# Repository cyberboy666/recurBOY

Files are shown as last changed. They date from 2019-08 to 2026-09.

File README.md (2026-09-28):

# recurBOY

### a rpi0 video-instrument – created in collaboration with Guergana Tzatchkova



- this circuit is distributed by __UNDERSCORES__ - _an open video hardware label_ : it is available to purchase - as a pcb, kit or assembled unit - at [underscores.shop](https://underscores.shop/recurboy/)
- the schematic for the circuit can be found [here](/hardware/schematic.pdf)
- the pcb gerber files for the lastest version can be found [here](/hardware/gerber_latest.zip)
- interactive BOM is [here](https://htmlpreview.github.io/?https://github.com/cyberboy666/recurBOY/blob/main/hardware/bom/ibom.html)
- link to latest rpi image is [here](https://github.com/cyberboy666/recurBOY/releases/latest)
- link to FAQ/TROUBLESHOOTING page can be found [here](https://github.com/cyberboy666/recurBOY/wiki/recurBOY-FAQ---TROUBLESHOOTING-guide)
- consider [donating](https://opencollective.com/underscores) to the underscores project to help us continue creating for the commons

## description

_recurBOY_ is a stand-alone digital video synthesizer and sampler. it can trigger clips and run shaders to create and manipulate sd video. 

- outputs sd video over composite or hdmi
- 2 source modes to generate video : sampler and shaders
- process any source with additional FX
- control shader/fx parameters directly with 4x knobs or externally with 4x cv inputs
- all inputs also controllable via usb-midi
- process external video through compatible usb capture cards / web-cams

## demo video

(https://videos.scanlines.xyz/w/5WkEcwTpqrN5Nh6LpczcTi)

## background

<details><summary>background</summary>

recurBOY was originally designed in 2019 by tim & guergana to be built together with others in group workshop soldering sessions - the design is a spinoff from [r_e_c_u_r](https://github.com/cyberboy666/r_e_c_u_r) an existing project tim created and maintains. r_e_c_u_r is simple to assemble but more complex to operate due to its scope and customizablity. recurBOY distills the best parts, aiming to be simpler and more beginner friendly. it uses cheaper parts and runs on a raspberry pi zero which can be a fraction the price of the pi3 used in r_e_c_u_r.

</details>

# documentation

this project is fully _open-source hardware_ - all the files required to build it are included in this repo for free. if you have the time and/or skill you can contribute back by collaborating on / testing new designs, improving these docs, making demo videos/other creative content etc. you can also support the project financially by [donating directing](https://opencollective.com/underscores), or purchasing through the [web shop](https://underscores.shop).

depending on whether you are going fully diy or buying an assembled and tested unit, some of the following guides will be relavent to you. the flow would be:

## ordering parts

<details><summary><b>parts sourcing guide (w/ notes on pcb fabracation )</b> - start here if you are building fully from scatch or have purchased a pcb</summary>

i try to source all the parts i can from either:
- [tayda](https://www.taydaelectronics.com/) ; cheaper for common parts like resistors etc, also good for mechanical parts like switches and buttons
- [mouser](https://www.mouser.de/) ; has lots more options, speciality video ic's, can sometimes cost more (free shipping on orders over 50euros)
- other ; ocationally there will be parts which will need to be sourced elsewhere - usaully either aliexpress, ebay or amazon etc...

take a look at the [full_bom](/hardware/bom/full_bom.csv) for this project to see where i am sourcing each part from

## import into tayda

- go to the [tayda quick order](https://www.taydaelectronics.com/quick-order/) and in bottom corner choose _add from file_
- select the file [tayda_bom.csv](./hardware/bom/tayda_bom.csv) in the BOM folder (you will have to download it first or clone this repo)
- after importing select _add to cart_
- __NOTE:__ the minimum value for resistors is 10, so you may need to modify these values to add to cart (or if they are already modified here you will need to see the  full_bom for actual part QTY) 

- OPTIONAL: it is a good idea to add some dip-ic sockets and 2.54pin headers/sockets to your tayda order if you dont have them around already
  
## import into mouser

- go to [mouser bom tool](https://nz.mouser.com/Bom/) and click _upload spreadsheet_
- select the file [mouser_bom.csv](./hardware/bom/mouser_bom.csv) in this folder (you will have to download it first or clone this repo), then _upload my spreadsheet_ and _next_
- ensure that __Mouser Part Number__ is selected in the dropdown above the first row, then _next_, _process_
- if everything looks correct can now put _add to basket_

## sourcing __other__ specific parts

the recurBOY has a few less common parts that can not be found at either tayda or mouser.

### 1.8 inch tft display (ST7735S)

i use have used [this seller](https://www.aliexpress.com/item/1005009712175802.html) and also [this one](https://www.aliexpress.com/item/1005006139989470.html) on _aliexpress_ - however there are many different brands with compatable products, both on ali, amazon and ebay etc...

to tell if a display you are looking at is compatable, check for the following things:
- 1.8inch in size (128x160px), rgb and tft - _not_ oled etc
- uses ST7735S driver over SPI
- pins order match the cuiisw one: __GND | VDD | SCL | SDA | RST | DC | CS | BLK__





for example, i can tell that the [waveshare](https://www.waveshare.com/1.8inch-lcd-module.htm) version is __NOT__ compatable, since although the size and type and driver all match, the _pin order is different_ (they break the pins out to: _BL | RST | DC | CS | CL | DIN | GND | VCC_ )

(this is a shame since i usually recommend waveshare as a reliable supply for these kinds of things if people are less happy to source through ali)

### 5 way tact switch

to save space on the interface we used [this 5 way tact switch](https://www.adafruit.com/product/504) (10x10mm through hole) - also sourced from [aliexpress](https://www.aliexpress.com/item/1005004357075585.html) - you can find these on other places such as amazon and ebay aswell.



main thing to look for here is that they are the right size, and the switch is through hole (tht) - as there are other surface mount versions around too.

### other parts to source

- 2x20 pin header [from tayda](https://www.taydaelectronics.com/2x20-pin-2-54mm-double-row-female-pin-header.html) if your rpi_zero doesnt come with this, + strip of [header pins](https://www.taydaelectronics.com/40-pin-2-54-mm-single-row-pin-header-strip.html) you can cut two from to solder onto the tv_out pins, 
- caps for the 12x12mm switches can be found on [tayda](https://www.taydaelectronics.com/electromechanical/switches-key-pad/tact-switch/round-tactile-push-button-cap-blue-color.html) in a few differnt colours. also can be got on ali/elsewhere
- caps for the 5way tact switch can also be found on [aliexpress](https://www.aliexpress.com/item/32810107963.html) or elsewhere Diameter: __8.5 MM * 10.5 MM high Inner hole: 3.1 * 3.1 MM__
- the __raspberry pi zero__ itself - see [here](/README.md#sourcing-and-preparing-the-raspberry-pi-zero)

# ordering pcbs

you can support this project by buying individual pcbs from the [shop](https://underscores.shop). if you would rather have pcbs fabricated from gerbers directly the file you need is [here](/hardware/gerber_latest.zip) 

- i get my pcbs fabricated from [jlcpcb](https://cart.jlcpcb.com/quote) - 5 is the minumum order per design
- upload the zip file with the `add gerber file` button
- the default settings are mostly fine - set the __PCB Qty__ and __PCB Color__ settings (you can check that the file looks correct with pcb veiwer)
- it may be best to combine orders with other pcbs you want to have fab'd since the shipping can cost more than the items - also orginising group buys is a good way to distribute the extra pcbs /costs 
  
i often use jlcpcb because they are reliable, cheap and give you an option of colours. remember though that the cheapest Chinese fab houses are not always the most ethical or environmently friendly - if you can afford it consider supporting local companies. 

</details>

## assembly guide

<details><summary><b>assembly guide</b> - start here if you have purchased a diy kit</summary>

## interactive BOM for build guiding

follow this link to view the [interactive BOM](https://htmlpreview.github.io/?https://github.com/cyberboy666/recurBOY/blob/main/hardware/bom/ibom.html)

## general solder advices

- remember to heat pad first (2-3seconds), then add solder, then continue to heat (1-2seconds)

- Checkout the web-comic [soldering is easy](https://mightyohm.com/files/soldercomic/FullSolderComic_EN.pdf) for more soldering advice
  
## specific assembly advice

### Step 1: R1 - R4, D1 - D8
start by placing the resistors and diodes. it is important that the diodes are placed in the correct direction ! for resistors it does not matter.

### Step 2: J8, J6
there are two parts that need to be placed from the bottom. this is so the raspberry pi can be attached underneath. turn the board over and find j8 - the 2x20 pin socket will connect to the pi0 gpio pins. it is very important that these are soldered on straight. next to this is j6 – a double pin socket that will connect to the pi0 tv out.

### Step 3: U1, SW1-5, J9
flip back to the front. now you can solder the ic and buttons. use the ic socket. also try to make sure the 5-way button is straight before soldering all the pins

### Step 4: J5
for screen make sure the included 8x1 pin header is soldered to it first - with short pin end to the screen. then you can solder the screen - with long header pin ends through the recurBOY pcb.

### Step 5: J1-4, J7
next solder the top row of jacks and the RCA connector

### Step 6: RV1 - RV5
now you can solder the potentiometers.

you may need to also solder the 2x20 gpio-header to the raspberry pi and a 1x2 pin-header for the tv-out - then your raspberry pi should slot into the bottom of the pcb.

### flashing image to sd card

you can flash the recurBOY image to a sd card if you didnt get one from me, or to update its firmware.  download [the lastest image here](https://github.com/cyberboy666/recurBOY/releases) and install an image-flashing program like [etcher](https://www.balena.io/etcher/) - select the downloaded zip file and sdcard in the program and let it flash

</details>

## sourcing and preparing the raspberry pi zero

<details><summary><b>sourcing and preparing the raspberry pi zero</b></summary>

unless you purchase a [raspberry pi zero from __underscores__](https://underscores.shop/product/raspberry-pi-zero-1w/) along-side your assembled and tested _recurBOY_ unit you will need to source and prepare the raspberry pi zero yourself:
  
recurBOY was designed to work with the first generation of reaspberry pi zeros:
 
- __Raspberry Pi Zero__ (2015) - no csi port, not needed for recurBOY
- __Raspberry Pi Zero v1.3__ (2016) - same as above but with csi port
- __Raspberry Pi Zero W__ (2017) - added wifi and bluetooth - wifi can be useful for transfering files wirelessly but not needed
- __Raspberry Pi Zero WH__ (2018) - same as above but with the 2x20 header pre-soldered
  
with all of these versions you will need to solder a 2x1_pin_header to the tv_out pins on the rpi (in line with the gpio header) - this then connects to the recurboy pcb with 2x1_pin_socket soldered on underside of the board:
  

  
in 2021 rpi launched [__Raspberry Pi Zero 2 W__](https://www.raspberrypi.com/products/raspberry-pi-zero-2-w/) - this is an upgrade to the original series of pi zeros. I have tested these with recurBOY and they work very well - runs faster / smoother than with the original.
  
one difference with this new version however is that they no longer break out the tv_out to pins. for this version you will need to solder jumper wires onto the tv_out pads, which are on the bottom of the board, next to the hdmi port.

i recommend using an [angled 2x1_pin_header](https://www.taydaelectronics.com/40-pin-2-54-mm-angle-single-row-pin-header.html) and placing it first into the socket on the recurBOY - then take care to solder the correct wires (__tv_out__ + __gnd__ ) to the angled pins and pads under pi_zero2 - __in this picture BLACK is GND and RED is TV_OUT__

  

once soldered you can twist the pi_zero, attach the main gpio headers and tuck the wires under the protruding rca jack to keep them hidden:



</details>

## operating guide
  
<details><summary><b>operating guide</b> - start here if you have purchased an assembled unit</summary>



### NAVIGATION

recurBOY has 2 source modes : `sampler` & `shaders` . pressing the __MODE__
button will cycle through these modes. you can tell which mode is selected by looking at the title and colour of the display.

### CONTENT SELECTION

the _nav_button_ can be pressed UP , DOWN , LEFT, RIGHT and IN. we will not use the IN button for now. pressing UP and DOWN lets you scroll through the list of content - either samples or shaders depending on the MODE. pressing SELECT on a row will start playing it. the playing content will be highlighted on the display and the ▶️ play symbol will display next to the MODE.

pressing the play/pause button will toggle this state. when the content is stopped the ⏹ will be displayed.

to safely turn off recurBOY hold down the play/pause button for 5 seconds. it is not recommended to remove your usb-drive while recurBOY is operating.

### Videos

the content list while in sampler MODE comes from the `~/Videos` folder on the pi's SD card and the `/Videos` folder on top level of an attached usb-drive. any .mp4, .mkv, .avi or .mov file will be shown although it is not guaranteed it will work with the player - we find sd h264 mp4 to be most reliable.

### Shaders

the content list while in the shaders MODE comes from the `~/Shaders` folder on the pi and in the `/Shaders` folder on top level of an attached device.

while the display is in SHADER mode you can use the 4 knobs or CV inputs to manipulate the shader parameters. each shader has 3 parameters mapped to input 0, 1 and 2. input 3 always controls the speed.



### Fx

from any source mode (SAMPLER or SHADERS) you can press the RIGHT nav_button to enter FX mode. This mode applies effects or filters to the media that is currently playing. Once you enter FX mode, you can navigate the same way as in SAMPLER or SHADERS with UP, DOWN and start the effect with SELECT. pressing LEFT will return to the previous screen.

these shaders need to be stored at `~/Fx` folder on the pi and `/Fx` folder on top level of attached usb drive. pressing the FX button will toggle the selected effect on and off. this effect will process whichever of the sources is selected.

the 4 knobs / cv inputs will control parameters of the effect when source SHADERS mode is not selected.

### Capture

if recurBOY is powered up with a compatible usb-capture card/web-cam plugged into the OTG data_usb input then a third SOURCE MODE will appear when MODE BUTTON is cycled through. within this mode you can start the _capture_ which will take video from this external device and send it through the FX MODES for processing

</details>

### more info

<details><summary><b>switching between pal and ntsc</b></summary>

- to switch the video format that your recurBOY uses, power down the device and put the sd card into a computer.
- now inside the `boot` partition look for a file called `config.txt`
- open it with any text editor and search for `sdtv_mode`
- here you can switch between `0` for _normal ntsc_ and `2` for _normal pal_
- save the file, safely eject the sd and put it back into the pi
- see [docs](https://www.raspberrypi.com/documentation/computers/config_txt.html#sdtv_mode) here for more settings

</details>

<details><summary><b>what are shaders anyway?</b></summary>
  
shaders are small text files of code that tell a graphics card what to draw. they use a language called glsl to communicate what colour a pixel should be and where. you don't have to understand every line to begin playing around with them.

in recurBOY we use shaders in two places - the SHADERS mode is used for launching shaders that generate video. these shaders take no video inputs. we also use shaders in the FX mode. here we are selecting shaders that process video. these take one video source as input and pass it through the fx shader.

the type of shader recurBOY can play is called GLES. this is the shader language used for embedded systems, including raspberry pi's and mobile phones.



thanks to [Erogenous Tones](http://erogenous-tones.com/) - a modular synth company who have a
mature and very powerful shader-playing video instrument called STRUCTURE - we now also have a web-based environment for browsing, modifying and creating shaders to perform with.

go to [glsl.erogenous-tones.com](http://glsl.erogenous-tones.com) - if you select any example you will see the code used to create the patch. try changing some of the numbers - modifying the input parameters is especially interesting.

when you are happy with the results select the save as .glsl file. Now copy this file onto your USB in the correct folder - /Shaders and connect to recurBOY

for more information on understanding and writing shaders yourself check out [The Book of Shaders](https://thebookofshaders.com/) by Gonzalez Vivo.
                                                                                                                             
</details>

<details><summary><b>how the circuit works</b></summary>
  
### reading button presses

we can use some of the GPIO pins on the raspberry pi to know when a button is pressed. one side of the button is connected to the pin and the other is connected to ground. on the raspberry pi we tell these pins to pull up. this means they are HIGH by default. when the button is pressed however the circuit connecting the pin to ground is completed and the pin becomes LOW. in the code we ask the state of a GPIO pin and if LOW we know the button is pressed.



### reading continuous inputs

digital pins - HIGH/LOW are good for discrete inputs like button presses which can only be OFF/ON. however we also want to have continuous inputs for example from knobs which can be set to any amount between LOW and HIGH. this kind of input is called analog - the reading is analogous to the voltage on the pin. since raspberry pi has no analog GPIO pins we need to introduce a new part - the MCP3008. this type of ic is called an analog to digital converter or adc for short. it has 8 analog pins which read the voltage applied to them and converts it to digital information. this information can be understood by the raspberry pi's digital pins. in this case using a digital protocol called SPI.

### potentiometers

four of the MCP3008 channels are connected to potentiometers which in this circuit act as voltage dividers. one side of the pot is connected to
+5V and the other to GND. The output is always some voltage between these. after passing through the adc this voltage value between GND and +5V is converted to a number between 0 and 1024



### cv inputs

the other four MCP3008 channels are connected to 3.5mm jacks. this allows the voltage to be set by external devices - this kind of interaction between instruments is called Control Voltage or CV each of the CV inputs also use a resistor and two diodes - these are to protect the IC from incoming voltages above +5V or below GND



### display

the raspberry pi also connects to the display screen with GPIO pins - this time the pins are used as outputs, telling the screen which pixels to colour - again the protocol used here is SPI - but we dont need to worry about how exactly this works - there is a python library that is used to describe what the screen should show
                                                                                                                             
</details>

<details><summary><b>contributing guide</b></summary>
  
if you would like to contribute back to these projects in some way but dont know how the best thing (for now) would be to reach out to me directly ( tim@cyberboy666.com or @cyberboy666 on scanlines forum) - i will be happy to help
  
</details>

## credits & more info

This circuit is distributed through UNDERSCORES – open video hardware label – visit [underscores.shop](https://underscores.shop) for more info

The pcb was designed using KICAD

Everything from gerbers, cad files, panels and documentation is freely available online and distributed under CC-BY-SA / open-source licenses – help us contribute to the commons !

Ask any questions or start discussions related to this project on the [scanlines.xyz](https://scanlines.xyz) forum – an online community space dedicated to diy av / electronic media art

You can contact me directly at tim (at) cyberboy666 (dot) com 
Please get in touch if you are interested in hosting a workshop !



Thanks to Guergana Tzatchkova for all the love put into creating this project, and the design inspiration used across my work. to Bastien Lavaud for circuit advice, always. To Ben Caldwell for project advice. To everyone who has or will contribute ♥♥♥

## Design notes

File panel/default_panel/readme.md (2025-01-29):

# recurboy default_panel notes

- the mounting holes fit m3 screws
- the front_panel mounts to pcb with 10mm standoffs
- 35mm screws will fit top of front_panel, pcb and support pi0 at angle pi0 - 15mm screws should fit bottom
- the default potentiometers in underscores BOMs have 12mm shaft lengths - consider replacing these with >17mm shaft length alternatives if you plan to use it with a panel

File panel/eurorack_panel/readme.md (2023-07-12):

# recurboy eurorack_panel notes

- the mounting holes fit m3 screws
- the front_panel mounts to pcb with 10mm standoffs
- this circuit has footprint for eurorack power header to be soldered to bottom of pcb (uses 5v rail only of 16 header)
- this panel includes UNTESTED YET mounting holes for usb and hdmi breakout cables
- this panel is 20HP
- the default potentiometers in underscores BOMs have 12mm shaft lengths - consider replacing these with >17mm shaft length alternatives if you plan to use it with a panel

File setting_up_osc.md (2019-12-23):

# Step 1. Set up your raspberry pi as a Wireless Access Point (maybe should be last step)

*Important! Make sure to do all this once you have downloaded all the packages (npm install, updates, etc) you need from internet, you won't be able to access the internet once you set up your Pi as a Wireless Access Point.* 

To set up your raspberry pi zero W as a wireless access point, [follow these instructions](https://www.raspberrypi.org/documentation/configuration/wireless/access-point.md).

# Step 2. Install Node on the raspberry pi

So first of all type this in your terminal on raspberry pi to detect the version that you need:

```uname -m```

If the response starts with armv6 than that's the version that you will need. For example for raspberry pi zero W you will need ARMv6

The latest version that supports armv6 is v.10.x, go to [Node's official website](https://nodejs.org/en/download/releases/) and download the tar.gz file that you need. 

In my case it was: [node-v10.17.0-linux-armv6l.tar.gz](https://nodejs.org/dist/latest-v10.x/node-v10.17.0-linux-armv6l.tar.gz) 

You can download the file either by doing (if your pi is connected to the internet): 

```wget https://nodejs.org/dist/latest-v10.x/node-v10.17.0-linux-armv6l.tar.gz```

or 

```curl -o node-v10.17.0-linux-armv6l.tar.gz https://nodejs.org/dist/latest-v10.x/node-v10.17.0-linux-armv6l.tar.gz```

or doing ssh into the pi and copying the files to the pi from the terminal of your computer:

```"C:\Program Files\PuTTY\pscp.exe" node-v10.17.0-linux-armv6l.tar.gz pi@192.168.4.1:/home/pi```

Then extract the file:

```tar -xzf node-v10.17.0-linux-armv6l.tar.gz```

Finally copy node to its final location and expose it as a global command:
```
cd node-v6.11.1-linux-armv6l/
sudo cp -R * /usr/local/
```

Now run: ```node -v``` to verify that node was installed correctly.

# Step 3. Install socket.io

If you haven't set up the wireless port yet, the connectivity of your Raspberry Pi W should work, in that case, type: 
```npm install socket.io --save``` and npm should install the package for you. 

or

If you didn't follow the steps in order, and you set up the Wireless Access Point before, you won't have access to internet, so you'll need to download the package on your computer, pass it through SSH to the Raspberry Pi and then install it from there.

The steps for that unfortunate case are:

1. Download [the zip file of socket.io from github.com](https://github.com/socketio/socket.io/)
2. Extract the zip file and go inside the folder in your terminal: ```cd socket.io-master```
3. Run ```npm install``` inside socket.io-master so you download all dependencies and generate the node_modules folder. 
4. In the *package.json* file add a ```"bundledDependencies"``` array with the names of all the packages listed in the ```"dependencies"``` property
In my case it ended up like this: 
```
"bundledDependencies": [
    "debug", "engine.io", "has-binary2", "socket.io-adapter", "socket.io-client", "socket.io-parser"
  ],
 ```
 This will put all the dependencies also inside of the tarball, because you won't have internet to download them in the offline pi. 
 
 5. Run  ```npm pack ``` in your terminal. This will generate a tarball (.tgz or tar.gz) file. 
 6. Transfer the tarball file to the pi via SSH from the terminal from the folder where the file is stored, I did ```"C:\Program Files\PuTTY\pscp.exe" socket.io-2.3.0.tgz pi@192.168.4.1:/home/pi```
 7. SSH into the PI with Putty and do ```ls```. Your tarball file should be listed there.
 8. Run ```npm install ./socket.io-2.3.0.tgz --save``` to install the library in offline mode. 

# Step 4. Install node-osc

Now we need to install a node osc package (there are plenty online) to be able to send OSC messages between the different parts of the app. We have chosen node-osc. 

If your Pi has connection to Internet do simply ```npm install node-osc --save``` in the root of the project. 

If your Raspberry Pi is offline we need, again, to take the long road:

1. [Download the node-osc zip](https://github.com/MylesBorins/node-osc).
2. Extract the file and go into the folder ```cd node-osc-current```
3. Run ```npm install```
4. Open the packages.json file and copy the names of the dependencies into an array in bundledDependencies like this: ```"bundledDependencies":["jspack", "osc-min"],``` (this may change for future versions, this is valid for version 4.1.4.
5. Run ```npm pack``` to get your tarball file. 
6. Copy the file over SSH from the computer terminal to the Pi with the command ```"C:\Program Files\PuTTY\pscp.exe" node-osc-4.1.4.tgz pi@192.168.4.1:/home/pi```
7. Inside the Raspberry Pi do:  ```npm install ./node-osc-4.1.4.tgz --save```. Phew!!

# Step 5. Install python-osc

Now we need to install the python library that will communicate with the Python project (in this case, r_e_c_u_r). 

This has to be done also on the Pi, if the Raspberry Pi is connected to the internet, do ```pip3 install python-osc``` in the folder project. Also copy the ```py-osc-server.py``` file to the folder project. 

If your rasppi is offline, you need to:

1. Download the [python-osc's zip file](https://pypi.org/project/python-osc/#files) on your computer
2. Transfer the file to the Raspberry pi with our accustomed ```"C:\Program Files\PuTTY\pscp.exe" etc...```. 
3. Type ```tar -xvf python-osc-1.7.3.tar.gz``` to uncompress the tar to a folder. 
4. Type ```pip3 install python-osc-1.7.3``` and you should be good to go. 

Now run ```python3 py-osc-server.py``` to have the OSC server listening for messages and do ```npm start``` (will run ```webserver.js```) to start up the node server.

# And Finally!!! 

When you connect to the address ```http://192.168.4.1:8000``` (or whatever port you have configured in webserver), you will be able to send messages to the node app, and from the node app to any application with OSC activated on port 5233 (defined in ```py-osc-server.py``` and in ```webserver.js```)

# Note:

As a final note I would like to add, that when working on an offline raspberry Pi, you can transfer files files from the Raspberry Pi to the Computer by typing from the terminal of the computer:  ```scp pi@193.168.4.1:myFolder/myFile.tar.gz .``` myFolder would be the path from ```/pi/home/```. This command will copy the file to the current director in the Terminal.

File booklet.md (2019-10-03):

# recurBOY

a raspberry pi zero video instrument

### motivation

__recurBOY__ is a raspberry pi zero based diy video-instrument for live performance.
it was designed to be built together with others in group workshop sessions.

for many people there is a barrier to enter the world of hardware video-art making instruments - both due to the general higher cost of video gear compared with audio equipment and in some cases its obsolescence and thus rarity.

this project aims to remove these financial barriers by enabling you to build your own art-making tools. by creating together we can learn from each other and help foster community in a physical space.

### features

- outputs sd composite video
- 2 source modes : _sampler_ and _shaders_
- process any source with additional _FX_
- control shader/fx parameters directly with 4x knobs or externally with 4x cv inputs

### origin of the project

the _recurBOY_ is a spinoff from an existing project tim has created and maintains - __r_e_c_u_r__ : _an open diy video sampler_ ; r_e_c_u_r is simple to assemble but can be more complex to operate due to its scope and customisablity. recurBOY distills the best parts, aiming to be simpler and more beginner friendly. it uses cheaper parts and runs on a raspberry pi zero which can be a fraction of the price of the pi3 used in r_e_c_u_r. 

### raspberry pi

a raspberry pi is a small computer - often referred to as a _Single Board Computer_ or SBC. it has 40 pins on it called _GPIOs_ - General Purpose In Out - which can be used to connect it with other components. the GPIO pins on the raspberry pi are _digital_ - this means that at any given time they can only be read as HIGH - 1 or LOW - 0. nothing in between. it also has a pin called `tv out` for outputting composite video.

### how was it made ?

the recurBOY application is built in __openframeworks__ - a collection of open-source c++ libraries for creative coding. in particular it uses _ofxVideoArtTools_ - an abstraction of openframeworks libraries and extensions into modules specifically for making video instruments on raspberry pi. integration with the TFT display is made in _python_. 

the pcb was designed in KiCad, an open source program for the design of electronic schematics and printed circuit boards

## build guide

the components should be soldered in this order.

ref | part
--- | ---
R1, R2, R3, R4 | 1k resistors
D1, D2, D3, D4, D5, D6, D7, D8 | bat85 diodes
J8 | Raspberry_Pi / 2x20 pin socket
J6 | Raspberry_Pi_TV_out
U1 | MCP3008 IC
J9 | 5-way push buton
SW1, SW2, SW3, SW4, SW5 | push buttons
J1, J2, J3, J4 | 3.5mm jacks
J7 | rca socket
RV1, RV2, RV3, RV4 | 10k potentiometers
J5 | 1.8" TFT display

__R1-4, D1-8__ : start by placing the resistors and diodes. it is __important__ that the _diodes_ are placed in the correct direction ! for resistors it does not matter.

__J8, J6__ : there are two parts that need to be placed __from the bottom__ . this is so the raspberry pi can be attached underneath. turn the board over and find j8 - the 2x20 pin socket will connect to the pi0 gpio pins. it is __very important__ that these are soldered on straight. start by soldering 1 or 2 pins from the header and then check it is perpendicular to the board - once multiple pins are soldered it is very difficult to correct the angle. next to this is j6 - a single pin socket that will connect to the pi0 tv out.

__U1, SW1-5, J9__ : flip back to the front. now you can solder the ic ans buttons. use the ic socket if you like. also try to make sure the 5-way button is straight before soldering all the pins

__J5__ : for screen make sure the included 8x1 pin header is soldered to the screen first - with short pin end to the screen. then you can solder the screen - with long header pin ends through the recurBOY pcb.

__J1-4, J7__ : next is the top row of jacks and the RCA connector

__RV1-4,__  : now you can solder the potentiometers.

if not already you will need to also solder the gpio-header to the raspberry pi and a single pin for the tv-out - then this should slot into the bottom of the pcb.

## operation guide

~~check that the raspberry pi is attached to the recurBOY pcb and the flashed micro-sd is inserted.~~

~~connect recurBOY to a tv via the rca jack in the top middle. now plug the micro-usb power supply into the raspberry pi power-jack - take care it is the power jack and not the usb.~~

~~you should see the display light up and recurBOY splash on the connected tv. wait a few moments for the pi to boot - the display should show a menu when ready.~~

to safely turn off recurBOY hold down the play/pause button for 5 seconds. it is not recommended to remove your usb-drive while recurBOY is operating.

### source selection

__recurBOY__ has 2 source modes : _sampler_ , _shaders_. pressing the `MODE` button will cycle through these modes.

you can tell which mode is selected by looking at the title and colour of the display.

### content selection

the nav_button can be pressed `UP` , `DOWN` , `LEFT`, `RIGHT` and `IN`. we will not use the `IN` button for now.

pressing `UP` and `DOWN` lets you scroll through the list of content - either samples or shaders depending on the MODE. pressing `SELECT` on a row will start playing it. the playing content will be highlighted on the display and the play symbol ▶ will display next to the MODE. pressing the play/pause button will toggle this state. when the content is stopped the ■ will be displayed. 

### samples

the content list while in _sampler_ MODE comes from the `~/Videos` folder on the pi's SD card and the `/Videos` folder on top level of an attached usb-drive. any .mp4, .mkv, .avi or .mov file will be shown although it is not guarenteed it will work with the player - we find sd h264 mp4 to be most reliable.

### shaders

the content list while in the _shaders_ MODE comes from the `~/Shaders` folder on the pi and in the `/Shaders` folder on top level of an attached device.

while the display is in __SHADER__ mode you can use the 4 knobs or CV inputs to manipulate the shader parameters. each shader has 3 parameters mapped to input 0, 1 and 2. input 3 always controls the speed.

### FX

from any source mode you can press the `RIGHT` nav_button to enter _fx_ mode. you can see this on the title of the display. same as elsewhere an _fx_ can be selected with `UP`, `DOWN` and `SELECT`. pressing `LEFT` will return to the selected _source mode_. these are read from `~/Fx` folder on the pi and `/Fx` folder on top level of attached usb drive.

pressing the `FX` button will toggle the selected _fx_ on and off. this _fx_ will process whichever of the sources is selected.

the 4 knobs / cv inputs will control parameters of the _fx_ when in _fx_ mode.

### what are shaders anyway ?

shaders are small text files of code that tell a graphics card what to draw. they use a language called _glsl_ to communicate what colour a pixel should be and where. you don't have to understand every line to begin playing around with them.

in recurBOY we use shaders in two places - the `SHADERS` mode is used for launching shaders that _generate_ video. these shaders take no video inputs. we also use shaders in the `FX`  mode. here we are selecting shaders that _process_ video. these take one video source as input and pass it through the _fx_ shader. 

the type of shader recurBOY can play is called GLES. this is the shader language used for embedded systems, including raspberry pi's and mobile phones.

thanks to Erogenous Tones - a modular synth company who have a mature and very powerful GLES-shader-playing video instrument called STRUCTURE , we now also have a web-based environment for browsing, modifying and creating GLES shaders to perform with.

go to glsl.erogenous-tones.com - if you select any example you will see the code used to create the patch. try changing some of the numbers - modifying the input parameters is especially interesting. when you are happy with the results select the `save as .glsl file` . now copy this file onto your USB in the correct folder -` /Shaders` and connect to recurBOY

for more information on understanding and writing shaders yourself check out _the book of shaders by Gonzalez Vivo_.

## how the circuit works

### reading button presses

we can use some of these GPIO pins on the raspberry pi to know when a button is pressed. one side of the button is connected to the pin and the other is connected to ground. on the raspberry pi we tell these pins to _pull up_. this means they are HIGH by default.

when the button is pressed however the circuit connecting the pin to ground is completed and the pin becomes LOW. in the code we ask the state of a GPIO pin and if LOW we know the button is pressed.

### reading continuous inputs

_digital pins_ - HIGH/LOW are good for discrete inputs like button presses which can only be OFF/ON. however we also want to have continuous inputs for example from knobs which can be set to any amount _between_ LOW and HIGH. this kind of input is called _analog_ - the reading is analogous to the voltage on the pin. 

since raspberry pi has no _analog_ GPIO pins we need to introduce a new ic - the __MCP3008__. this type of ic is called an _analog to digital converter_ or a2d for short. it has 8 _analog_ pins which read the voltage applied to them and converts it to digital information. this information can be understood by the raspberry pi's _digital_ pins. in this case using a digital protocol called SPI)

four of the MCP3008 channels are connected to potentiometers which in this circuit act as voltage dividers. one side of the pot is connected to +5V and the other to GND. the output is always some voltage between these.
after passing through the a2d this voltage value between GND and +5V is converted to a number between 0 and 1024.

the other four MCP3008 channels are connected to 3.5mm jacks. this allows the voltage to be set by external devices - this kind of interaction between instruments is called _Control Voltage_ or CV. each of the CV inputs also use a resistor and two diodes - these are to protect the IC from incoming voltages above +5V or below GND

### the display

the raspberry pi also connects to the display screen with GPIO pins - this time the pins are used as _outputs_ , telling the screen which pixels to colour - again the protocol used here is SPI - but we dont need to worry about how exactly this works - there is a python library that is used to describe what the screen should show.    

## extra information

~~if you like this device and want more features you can try building a r_e_c_u_r also - checkout the github or video guides online.~~

### bonus feature

~~camera~~ -> usb-capture

i expected to be able to use live input from raspberry pi camera with this instrument however the pi0 could not handle opening the camera in openframeworks. somewhat unexpectedly however the usb-capture i tried seemed to work for previewing - it was glitchy but usable (recording was too much though). feel free to try this bonus feature if you like. if you want to use recurBOY with a pi3 you can enable the camera / recording too !

to use live input from a raspberry pi camera first ensure it is attached correctly. if a camera is attached the _camera_ source will be available by pressing `MODE`. from here pressing `SELECT` will start showing the camera _preview_. ~~when previewing it is possible to press `SELECT` again to start and stop camera _record_. after recording has stopped it will be converted to h264 mp4 and saved in `~/Videos` to be launched in _sampler_ mode.~~

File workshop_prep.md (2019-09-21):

dear diary: 

:P

i just want to start some notes to keep track and plan for the first recurBOY workshop in OCTOBER. this is a little over 8 weeks from now. this is plently of time to get code working but not much room for wiggle if sourcing parts and pcbs cheaply from china.

for aliexpress parts it would be best to allow 5-6weeks max - although most get here faster you never know. for ciruit-boards, cheap from seeed should take max 4 weeks - this is the biggest risk as i dont know how many revisions i might need. prioty circuits arrive within a week but cost MUCH MUCH more maybe 4x the price or more.

for ali-express some parts i can order now, some need to be tested first - i should try to do these asap
given the ali-parts are confirmed the next step is to get started on the circuit board to allow time for revisions - even if the software is not finished need to start with hardware - i want to aim to have first revision send away in less than 2 weeks from now - maybe try to do it this weekend

ofcourse if needed i can pay more to get things faster closer to the deadline - i would like to have decided a cutoff date early so i know when to act fast.

a table of parts ordered, tested, recieved etc to come here soon plus more dates and deadlines tbc

## parts and their status :

the status flow might look something like this: `test ordered` -> `test arrived` -> `test checked` -> `bulk ordered` -> `bulk arrived` -> `bulk checked`

REF | NAME | COST | STATUS
--- | --- | --- | ---
na | [raspberry pi zero] | 5 |  `bulk ordered`
na | custom pcb 100x100mm | 1.8 | `r0.2 ordered`
na | [smaller screen (1.8"?)] | 3.5 | `bulk arrived`
na | 10-12 [push buttons + caps from china] | 1  | `bulk arrived`
na | 4 10k pots for analog input | 3 | `bulk arrived`
na | 4 [thonkicon jack] inputs | 1.5 | `bulk arrived`
na | [a2d (mcp3008) from china] | 2 | `bulk arrived`
na | few resistors + diodes (8 bat85 + 4 1kohm) | 2 | `bulk arrived`
na | few pin headers | 0.5 | `bulk arrived`
na | [composite video jack] | 1 | `bulk arrived`
na | [sd card 8gb] | 2 | `bulk arrived`
na | [power-adapter] |  4 |  `bulk arrived`
na | (optional) [raspi camera clone] | 7 | `bulk arrived` 
na | 5-way nav switch | 1.5 | `bulk arrived`

### 5 way push button

~~it might also be worth considering a [5-way push button] like this - saves on space , may make navigation more intuitave - prob will need a few more pins but that is ok `also bulk ordered`~~

### experiments to try:

some tech things to confirm:

- try getting the [1.8" display] running -> python first - maybe think about directly in of if time permits?
- reading button presses, direct and from matrix -> working with [pad4pi] package -> will then extend this to of

### problem with sourcing the pi0s cheap

~~i still need to order the pi0s~~, ~~it is not possible to bulk order pi0s~~ - ~~people will have to bring their own..~~ ~~waiting on the power supply to test how it works will the pi~~ i ordered some _too cheap to be true_ pi0s on ebay - lets see if they arrive / work ? the backup plan is to buy enough pi0s at the bulk price : around 12euros, and give people at the workshop the choice out of a 12euro pi0 now from me or a 5euro pi0 later they can buy themself ... 

things still left to order :
 - ~~pots and resisitors i will get from mouser i think : waiting till i test some other parts before ordering these incase the cheaper chips (for example) dont work~~
 - ~~will get other set of thonkiconn jacks~~ : ordered from modular-addict
 - ~~decide and order a cheap - ish power supply that will arrive on time ... (the one from ali i think will be too slow)~~ ordered 10 5euro powersupplys from ebay - should arrive by beginning of next week - i hope they work !!

# final pcb order deadline.

i have some stress about getting pcbs fabbed and delivered in time for this workshop. flight from berlin is oct 4th.

with fast shipping would still need to allow 14 days to get pcbs fabbed and arrive, which means the final cutoff for a second revision of the board is 18th september. since first revision hasnt been shipped yet, and is with slow post , it would need to get here at most in 3 weeks (this would give me a few days to do the soldering and make any needed revisions)
i think this is possible but also not so likely. also will need to aleast have enough parts to do this test build before mid september. 

what other options are there ? possibly to use the revision1 boards if possible (but then there is only 10 in total - one of which i will need to use as a test board but maybe can give away at the workshop ... )

## first r0.1_board problem:

currently r0.1 of the board has the _display_ on pins for __SPI0__ and the _a2d_ on pins for __SPI1__. however it seems the a2d code can only read from __SPI0__ , whereas the _display_ can read from both. a easy hardware fix is to swap these pins around on the scematic/layout however as mentioned above there may not be much time for a second revision of the board to arrive. if everything else on r0.1 boards are ok another backup plan is to manually cut and rewire traces on the r0.1 boards for the workshop.

## r0.1 boards arrived !

this took less time than i expected. i soldered the board together in 70mins. i think the workshop has two 3hour slots so hopefully this will be enough time for everyone. everything worked together suprizingly well. the only real problem is the spi1/spi0 problem i spotted earlier. otherwise the display, push buttons, a2d etc all are working ! woop (need to test the composite video output)

i will create a new revision of the board, some changes include:
- switching the spi ports around
- slightly resizing the button footprint
- labelling buttons with the silk-screen
- moving button placement around a little
- maybe moving resistor/diode placements around a little
- ordering more than 10 this time with fast postage

i also will order the mouser parts to make sure we have everything and enough spare parts.

some testing for example, the display, the a2d, the other parts i used in the build all worked...

## some performance problems

we have yet to test all the parts together on a pi0 but i am antisipating some performance optimizations needed.
some things to try:
- updating screen less / only when something changes
- reading from the a2d less
- not running the ui desktop at all - launch everything from console
- experimenting with different gpu/cpu splits

## update 20/09

besides the pi0s themself - which havnt arrived - will order some more this weekend - everything else should be here now - only the circuitboards which should arrive soon. there is still lots to do including finsihing the code, testing on a pi0, and making the build booklet

[raspberry pi zero]: https://www.berrybase.de/raspberry-pi-zero-v1.3
[smaller screen (1.8"?)]: https://www.aliexpress.com/item/32996979276.html
[a2d (mcp3008) from china]: https://www.aliexpress.com/item/32735896933.html
[push buttons + caps from china]: https://www.aliexpress.com/item/32826994795.html
[thonkicon jack]: https://modularaddict.com/pj301m12-jacks
[sd card 8gb]: https://www.aliexpress.com/item/33040093922.html
[composite video jack]: https://www.mouser.de/ProductDetail/CUI/RCJ-024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
[power-adapter]: https://www.aliexpress.com/item/32898334338.html
[raspi camera clone]: https://www.aliexpress.com/item/32825264717.html
[5-way push button]: https://www.aliexpress.com/item/32845147449.html
[1.8" display]: https://jakew.me/2018/01/19/st7735-pi/
[pad4pi]: https://github.com/brettmclean/pad4pi/

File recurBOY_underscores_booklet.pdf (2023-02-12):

### cyberboy666 & underscores.shop present

### a circuit designed with guergana tzatchkova

# _recurBOY_

## rpi_zero video instrument

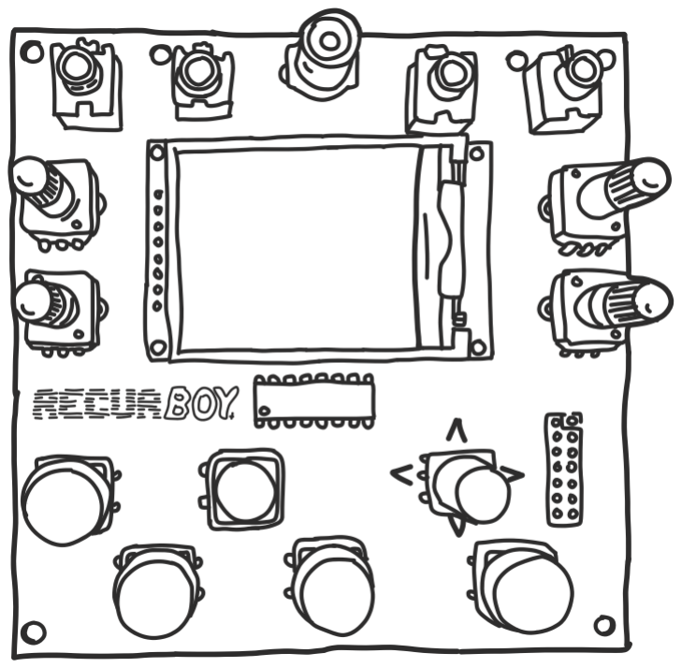
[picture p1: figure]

## underscores.shop edition instruction manual and build guide V0_7_1

View this project online at underscores.shop/recurboy

# BACKGROUND

recurBOY is a raspberry pi based diy video-instrument for live performance. it was originally designed by tim & guergana to be built together with others in group workshop soldering sessions

The design is a spinoff from r_e_c_u_r an existing project tim created and maintains. r_e_c_u_r is simple to assemble but more complex to operate due to its scope and customizablity. recurBOY distills the best parts, aiming to be simpler and more beginner friendly. it uses cheaper parts and runs on a raspberry pi zero which can be a fraction the price of the pi3 used in r_e_c_u_r.

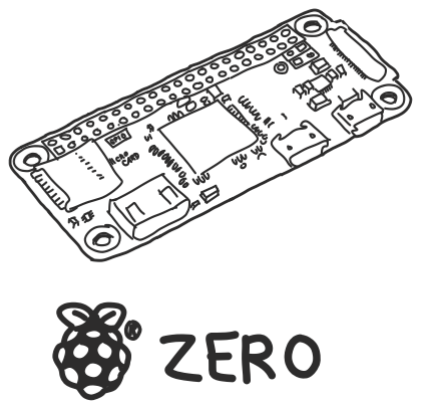
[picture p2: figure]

HOW WAS IT MADE ?

the recurBOY application is built in openframeworks – a collection of open-source c++ libraries for creative coding. In particular it uses ofxVideoArtTools - an abstraction of openframeworks libraries and extensions into modules specifically for making video instruments on raspberry pi. integration with the TFT display is made in python.

FEATURES

- outputs sd composite video
- 2 source modes : sampler & shaders
- process any source with additional FX
- control shader/fx parameters directly

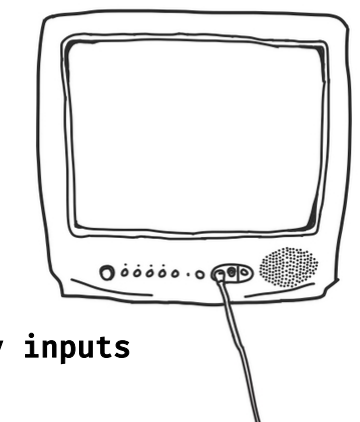
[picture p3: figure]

with 4x knobs and externally with 4x cv inputs

RASPBERRY PI ?

a raspberry pi is a small computer – often referred to as a Single Board Computer or SBC. it has 40 pins on it called GPIOs - General Purpose In Out -which can be used to connect it with other components. it also has a pin called tv_out for outputting composite video.

Your rpi0 must be sourced separately

# BUILD INSTRUCTIONS

It is highly recommended to use the interactive BOM to help with placement on this build – type kutt.it/iccIqU into a browser or find the links from the github page - components should be soldered in this order:

Step 1: R1 - R4, D1 - D8
start by placing the resistors and diodes. it is important that the diodes are placed in the correct direction ! for resistors it does not matter.
Step 2: J8, J6
there are two parts that need to be placed from the bottom. this is so the raspberry pi can be attached underneath. turn the board over and find j8 - the 2x20 pin socket will connect to the pi0 gpio pins. it is very important that these are soldered on straight. next to this is j6 – a double pin socket that will connect to the pi0 tv out.
Step 3: U1, SW1-5, J9
flip back to the front. now you can solder the ic and buttons. use the ic socket. also try to make sure the 5-way button is straight before soldering all the pins
Step 4: J5
for screen make sure the included 8x1 pin header is soldered to it first - with short pin end to the screen. then you can solder the screen - with long header pin ends through the recurBOY pcb. There is mounting holes for securing the other side of screen in place, or you could slide a small piece of foam under to hold it flush
Step 5: J1-4, J7
next solder the top row of jacks and the RCA connector
Step 6: RV1 - RV5
now you can solder the potentiometers.

you may need to also solder the 2x20 gpio-header to the raspberry pi and a 1x2 pin-header for the tv-out - then your raspberry pi should slot into the bottom of the pcb.

flashing image to sd card
you can flash the recurBOY image to a sd card if you didnt get one from me, or to update its firmware by running a program like balena etcher – links to downloading the image file can be found on project github page

# OPERATING INSTRUCTIONS

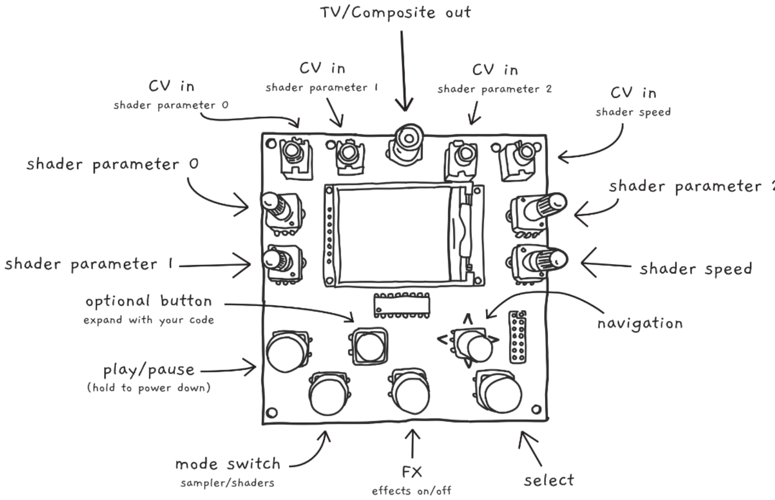
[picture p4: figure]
cvbs out; shader_parameter_0; shader_parameter_1; shader_speed; shader_parameter_3; CV in shader_parameter_1; CV in shader_parameter_2; CV in shader_speed; CV in shader_parameter_0; navigation; select; effects on/off; mode; sampler/shaders; play/pause; hold to power down; extra button; expand w your code

NAVIGATION

recurBOY has 2 source modes : sampler & shaders. pressing the MODE button will cycle through these modes. you can tell which mode is selected by looking at the title and colour of the display.

CONTENT SELECTION

the nav_button can be pressed UP , DOWN , LEFT, RIGHT and IN. we will not use the IN button for now. pressing UP and DOWN lets you scroll through the list of content - either samples or shaders depending on the MODE. pressing SELECT on a row will start playing it. the playing content will be highlighted on
the display and the play symbol will display next to the MODE. pressing the play/pause button will toggle this state. when the content is stopped the will be displayed.

to safely turn off recurBOY hold down the play/pause button for 5 seconds. it is not recommended to remove your usb-drive while recurBOY is operating.

OPERATING INSTRUCTIONS CONT.
Videos

the content list while in sampler MODE comes from the ~/Videos folder on the pi's SD card and the /Videos folder on top level of an attached usb-drive. any .mp4, .mkv, .avi or .mov file will be shown although it is not guaranteed it will work with the player - we find sd h264 mp4 to be most reliable.

Shaders

the content list while in the shaders MODE comes from the ~/Shaders folder on the pi and in the /Shaders folder on top level of an attached device.

while the display is in SHADER mode you can use the 4 knobs or CV inputs to manipulate the shader parameters. each shader has 3 parameters mapped to input 0, 1 and 2. input 3 always controls the speed.

Fx

from any source mode (SAMPLER or SHADERS) you can press the RIGHT nav_button to enter FX mode. This mode applies effects or filters to the media that is currently playing. Once you enter FX mode, you can navigate the same way as in SAMPLER or SHADERS with UP, DOWN and start the effect with SELECT. pressing LEFT will return to the previous screen.

these shaders need to be stored at ~/Fx folder on the pi and /Fx folder on top level of attached usb drive. pressing the FX button will toggle the selected effect on and off. this effect will
process whichever of the sources is selected.

the 4 knobs / cv inputs will control parameters of the effect when source SHADERS mode is not selected.

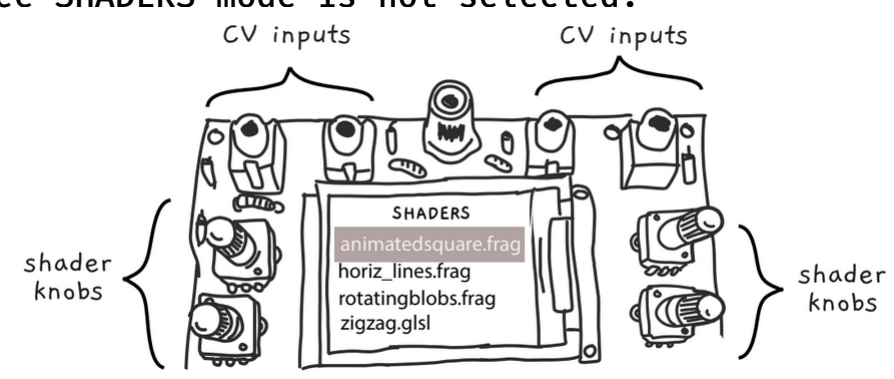
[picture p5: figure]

# WHAT ARE SHADERS ANYWAY?

shaders are small text files of code that tell a graphics card what to draw. they use a language called glsl to communicate what colour a pixel should be and where. you don't have to understand every line to begin playing around with them.

in recurBOY we use shaders in two places - the SHADERS mode is used for launching shaders that generate video. these shaders take no video inputs. we also use shaders in the FX mode. here we are selecting shaders that process video. these take one video source as input and pass it through the fx shader.

the type of shader recurBOY can play is called GLES. this is the shader language used for embedded systems, including raspberry pi's and mobile phones.

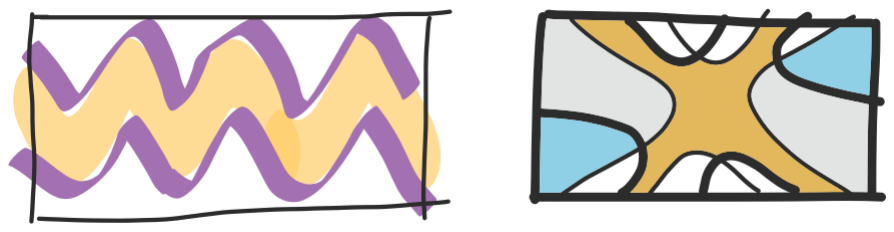
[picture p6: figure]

thanks to Erogenous Tones - a modular synth company who have a mature and very powerful shader-playing video instrument called STRUCTURE - we now also have a web-based environment for brows-ing, modifying and creating shaders to perform with.

go to glsl.erogenous-tones.com - if you select any example you will see the code used to create the patch. try changing some of the numbers - modifying the input parameters is especially interesting.

when you are happy with the results select the save as .glsl file. Now copy this file onto your USB in the correct folder -/Shaders and connect to recurBOY

for more information on understanding and writing shaders yourself check out The Book of Shaders by Gonzalez Vivo.

## HOW THE CIRCUIT WORKS

reading button presses
we can use some of the GPIO pins on the raspberry pi to know when a button is pressed. one side of the button is connected to the pin and the other is connected to ground. on the raspberry pi we tell these pins to pull up. this means they are HIGH by default.
when the button is pressed however the circuit connecting the pin to ground is completed and the pin becomes LOW. in the code we ask the state of a GPIO pin and if LOW we know the button is pressed.

reading continuous inputs
digital pins - HIGH/LOW are good for discrete inputs like button presses which can only be OFF/ON. however we also want to have continuous inputs for example from knobs which can be set to any amount
between LOW and HIGH. this kind of input is called analog - the reading is analogous to the voltage on the pin.
since raspberry pi has no analog GPIO pins we need to introduce a new part - the MCP3008. this type of ic is called an analog to digital converter or adc for short. it has 8 analog pins which read the voltage applied to them and converts it to digital information. this information can be understood by the raspberry pi's digital pins. in this case using a digital protocol called SPI.

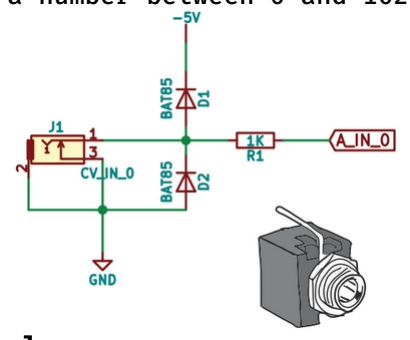
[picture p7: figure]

display

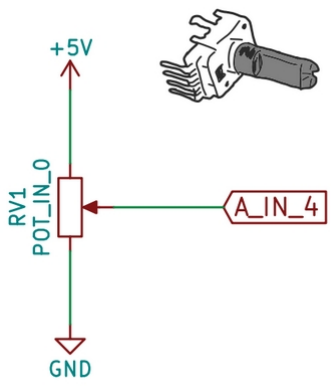
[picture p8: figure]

the raspberry pi also connects to the display screen with GPIO pins -this time the pins are used as outputs, telling the screen which pixels to colour - again the protocol used here is SPI - but we dont need to worry about how exactly this works - there is a python library that is used to describe what the screen should show.

cv inputs

the other four MCP3008 channels
are connected to 3.5mm jacks. this
allows the voltage to be set by external devices - this kind of interaction between instruments is called Control Voltage or CV each of the CV inputs also use a resistor and two diodes - these are to protect the IC from incoming voltages above +5V or below GND

potentiometers
four of the MCP3008 channels are connected to potentiometers which
in this circuit act as voltage dividers. one side of the pot is connected to
+5V and the other to GND. The output is always some voltage between these. after passing through the adc this voltage value between GND and +5V is converted to a number between 0 and 1024.

# CREDITS AND MORE INFO

This circuit is distributed through UNDERSCORES – an open video hardware label – visit underscores.shop for more info

The pcb was designed using KICAD , this booklet was created in LibreOffice Draw

Everything from gerbers, cad files, panels and documentation is freely available online and distributed under CC-BY-SA / open-source licenses – help us contribute to the commons !

Ask any questions or start discussions related to this project on the scanlines.xyz forum – an online community space dedicated to diy av / electronic media art

You can contact me directly at tim (at) cyberboy666 (dot) com Please get in touch if you are interested in hosting a workshop !

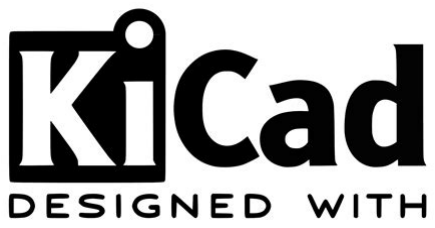
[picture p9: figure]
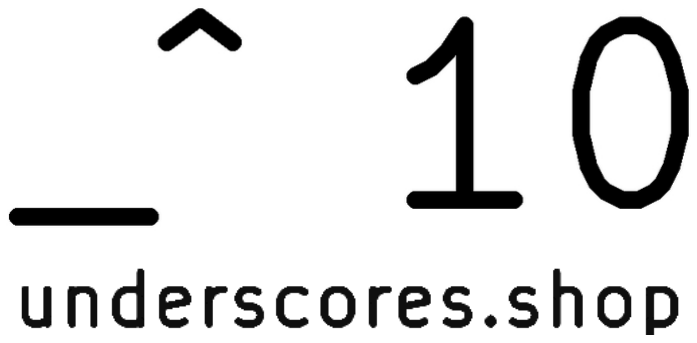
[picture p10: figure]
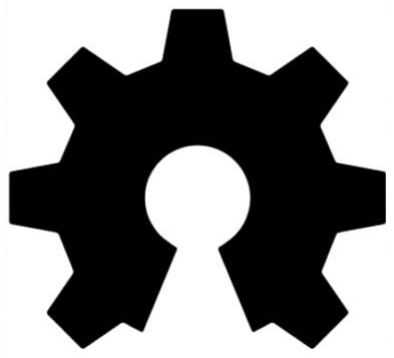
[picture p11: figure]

Thanks to Guergana Tzatchkova for all the love put into creating this project, and the design inspiration used across my work. to Bastien Lavaud for circuit advice, always. To Ben Caldwell for project advice. To everyone who has or will contribute ♥♥♥

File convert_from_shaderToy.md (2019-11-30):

If you want to add your own shaders to recurBOY from shadertoy, you have to convert them manually to GLES.

# HelloShaderCircle

We took this simple example from Shadertoy
[A Simple Circle](https://www.shadertoy.com/view/XsjGDt)

## ShaderToy Default Variables:

The ShaderToy variable names are slightly different from the ones in GLSL Sandbox. The default variables are:

```
uniform vec3      iResolution;           // viewport resolution (in pixels)
uniform float     iTime;                 // shader playback time (in seconds)
uniform float     iTimeDelta;            // render time (in seconds)
uniform int       iFrame;                // shader playback frame
uniform float     iChannelTime[4];       // channel playback time (in seconds)
uniform vec3      iChannelResolution[4]; // channel resolution (in pixels)
uniform vec4      iMouse;                // mouse pixel coords. xy: current (if MLB down), zw: click
uniform samplerXX iChannel0..3;          // input channel. XX = 2D/Cube
uniform vec4      iDate;                 // (year, month, day, time in seconds)
uniform float     iSampleRate;           // sound sample rate (i.e., 44100)
```

## ShaderToy Original Example:

```
/**
 * @author jonobr1 / http://jonobr1.com/
 */

/**
 * Convert r, g, b to normalized vec3
 */
vec3 rgb(float r, float g, float b) {
	return vec3(r / 255.0, g / 255.0, b / 255.0);
}

/**
 * Draw a circle at vec2 `pos` with radius `rad` and
 * color `color`.
 */
vec4 circle(vec2 uv, vec2 pos, float rad, vec3 color) {
	float d = length(pos - uv) - rad;
	float t = clamp(d, 0.0, 1.0);
	return vec4(color, 1.0 - t);
}

void mainImage( out vec4 fragColor, in vec2 fragCoord ) {

	vec2 uv = fragCoord.xy;
	vec2 center = iResolution.xy * 0.5;
	float radius = 0.25 * iResolution.y;

    // Background layer
	vec4 layer1 = vec4(rgb(210.0, 222.0, 228.0), 1.0);
	
	// Circle
	vec3 red = rgb(225.0, 95.0, 60.0);
	vec4 layer2 = circle(uv, center, radius, red);
	
	// Blend the two
	fragColor = mix(layer1, layer2, layer2.a);

}
```

## Final version in GLSLSandbox (recurBOY) format:

you have to change the variable names from fragCoord to gl_fragCoord and other ones like time to itime. Also the parameters f0, f1 and f2 won't be there so you have to add them yourself. 

```
precision mediump float;

varying vec2 tcoord;    // location
uniform sampler2D tex;  // texture one
uniform sampler2D tex2; // texture two
uniform vec2 tres;      // size of texture (screen)
uniform vec4 fparams;   // 4 floats coming in
uniform ivec4 iparams;  // 4 ints coming in
uniform float ftime;    // 0.0 to 1.0
uniform int itime;      // increases when ftime hits 1.0
//f0::
//f1::
//f2::
float f0 = mix(0.05, 0.95, fparams[0]);
float f1 = mix(0.05, 0.95, fparams[1]);
float f2 = mix(0.05, 0.95, fparams[2]);

float time = float(itime) + ftime;
vec2 resolution = tres;

/**
 * Convert r, g, b to normalized vec3
 */
vec3 rgb(float r, float g, float b) {
	return vec3(r / 255.0, g / 255.0, b / 255.0);
}

vec4 circle(vec2 uv, vec2 pos, float rad, vec3 color) {
	float d = length(pos - uv) - rad;
	float t = clamp(d, 0.0, 1.0);
	return vec4(color, 1.0 - t);
}

void main( void ) {
    	
	vec2 uv = gl_FragCoord.xy;
	vec2 center = resolution.xy * 0.5;
	float radius = 0.25 * resolution.y * f1;

    // Background layer
	vec4 layer1 = vec4(rgb(210.0, 222.0, 228.0), 1.0);
	
	// Circle
	vec3 red = rgb(mix(0.0, 255.0, f2),0.0, 0.0);
	vec4 layer2 = circle(uv, center, radius, red);
	
	// Blend the two
	gl_FragColor = mix(layer1, layer2, layer2.a);
}
```

The best way to do it is to click "create new shader" in [http://glsl.erogenous-tones.com/](http://glsl.erogenous-tones.com/) and paste the shadertoy code and start doing the changes there, that way you can test if your code renders the shader. 

Make sure that you define the functions and variable names before you use them. Otherwise you will get errors.

Main differences:

shadertoy | glslsandbox - recurboy
--- | ---
void mainImage( out vec4 fragColor, in vec2 fragCoord ) | void main( void )
fragColor | gl_FragColor
fragCoord | gl_FragCoord
iTime | time
iResolution | resolution

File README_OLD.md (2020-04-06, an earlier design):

# recurBOY

__recurBOY__ is a raspberry pi zero based diy video-instrument for live performance.

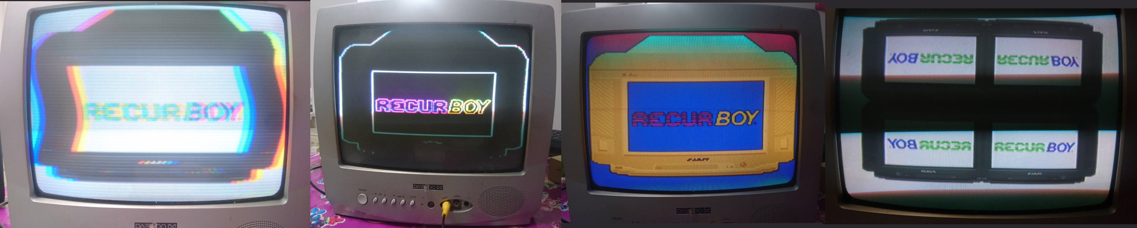
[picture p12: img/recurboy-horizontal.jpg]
recurBoy


### motivation

it was designed to be built together with others in group workshop sessions.

for many people there is a barrier to enter the world of hardware video-art making instruments - both due to the general higher cost of video gear compared with audio equipment and in some cases its obsolescence and thus rarity.

this project aims to remove these financial barriers while enabling anyone interested to build their own art-making tools. by creating together we can learn from each other and help foster community in a physical space.

### features

- outputs composite video
- 2 source modes : _sampler_ and _shaders_
- process any source with additional _FX_
- control shader/fx parameters directly with 4x knobs or externally with 4x cv inputs

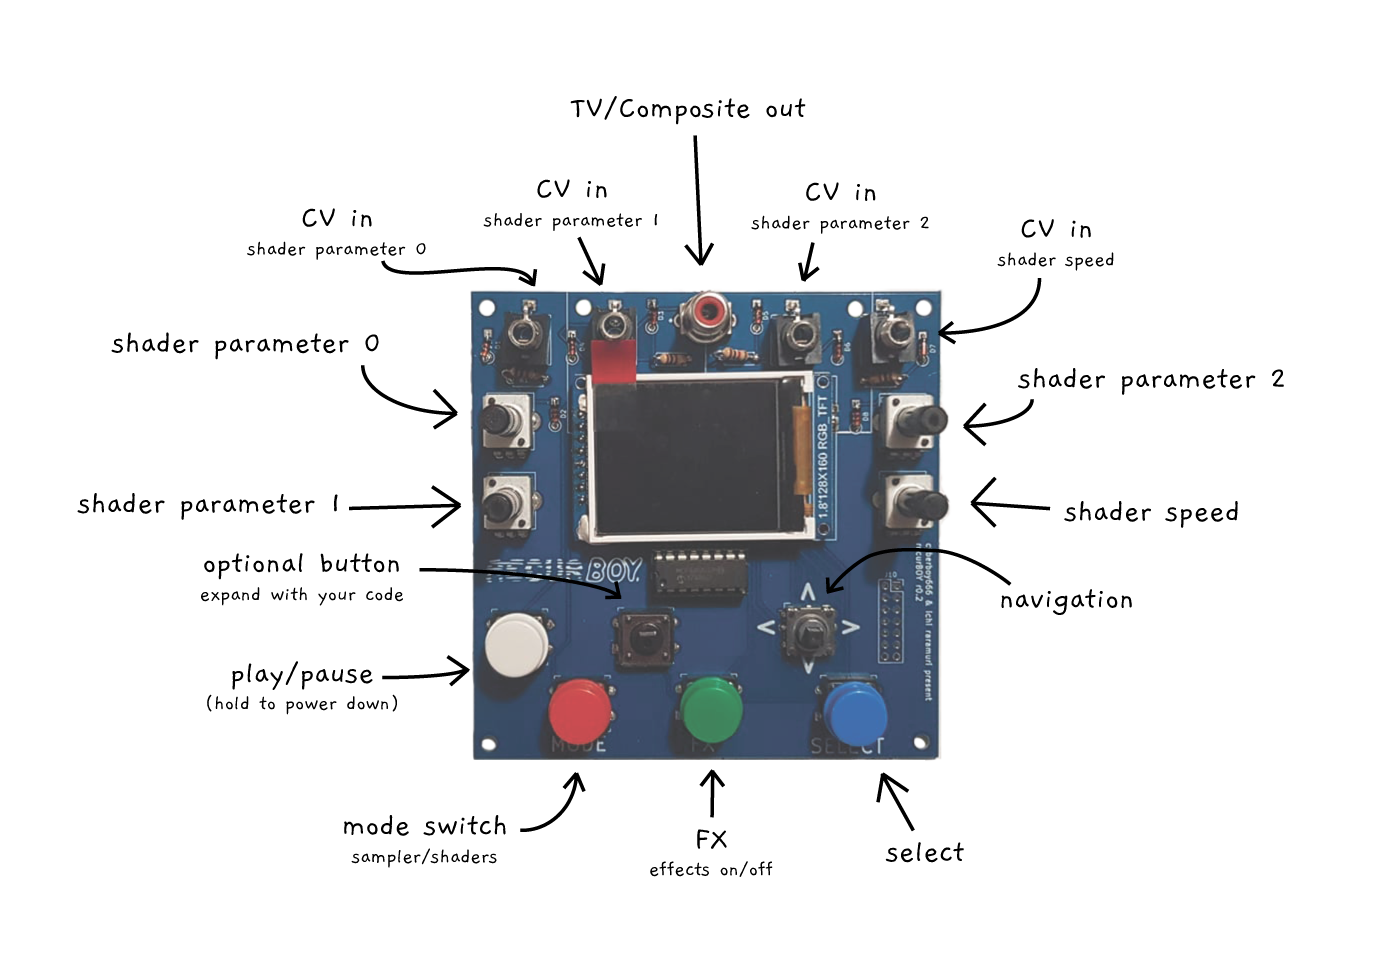
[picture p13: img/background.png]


## BOM

REF | NAME | NUMBER | REF | APROX COST (euro)
--- | --- | --- | --- | ---
na | [raspberry pi zero] | 1 | NA | 5, 12 - 18
na | custom pcb 100x100mm | 1 | NA | 5
J5 | [1.8" screen] | 1 | NA | 4
SW1-5 | [push buttons + caps] | 5 | NA | 1 
RV1-4 | 10k linear pots | 4 | PTV09A-4025UB103 (mouser) | 3
J1-4 | [thonkicon jack] inputs | 4 | A-2563  | 2
U1 | [mcp3008 a2d dip] | 1 | A-2470 | 2
U1 | IC 16pin socket | 1 | A-003 | 0.5
R1-4 | 1k resistors | 4 | A-3772 | 0.5
D1-8 | bat46 diodes| 8 | A-1095 | 2
J8 | 2x20 pin header | 1 in 1 out | A-195 , 1/2 of A-196 | 1
J7 | [composite video jack] | 1 | 490-RCJ-024 (mouser) | 1
na | [sd card 8gb] | 1 | NA | 2 |
na | power-adapter | 1 | A-3167 (US) , A-3166 (EU) |  5
J9 | [5-way push button] | 1 | NA | 1.5

[cheaper 5-way push buttons](https://www.aliexpress.com/item/32998891073.html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)

aprox total cost : 30euro plus the raspi0 - can get for 5euro from some distributors

additional parts:

- 1-pin header and socket for tv-out
- DIP8 ic socket
- usb-micro to USB-A socket to attach usb
- USB drive
- a rca cable
- a composite tv, display or mixer
- some M2 screws, nuts and spacers

[raspberry pi zero]: https://www.berrybase.de/raspberry-pi-zero-v1.3
[1.8" screen]: https://www.aliexpress.com/item/32996979276.html
[mcp3008 a2d dip]: https://www.aliexpress.com/item/32735896933.html
[push buttons + caps from china]: https://www.aliexpress.com/item/32826994795.html
[thonkicon jack]: https://modularaddict.com/pj301m12-jacks
[sd card 8gb]: https://www.aliexpress.com/item/33040093922.html

[composite video jack]: https://www.mouser.de/ProductDetail/CUI/RCJ-024
[5-way push button]: https://www.aliexpress.com/item/32845147449.html

## FAQ:

### How can you load your own video files

1. You need to create a folder called `Videos` in the root of the usb stick. 

2. This is where the usb cable goes if you are looking at the recurBoy from the front. It has to be on the right side of the raspberrypi zero. You will need the usb adapter that's part of your kit. The usb stick needs to be inserted BEFORE you turn on your recurBoy. 

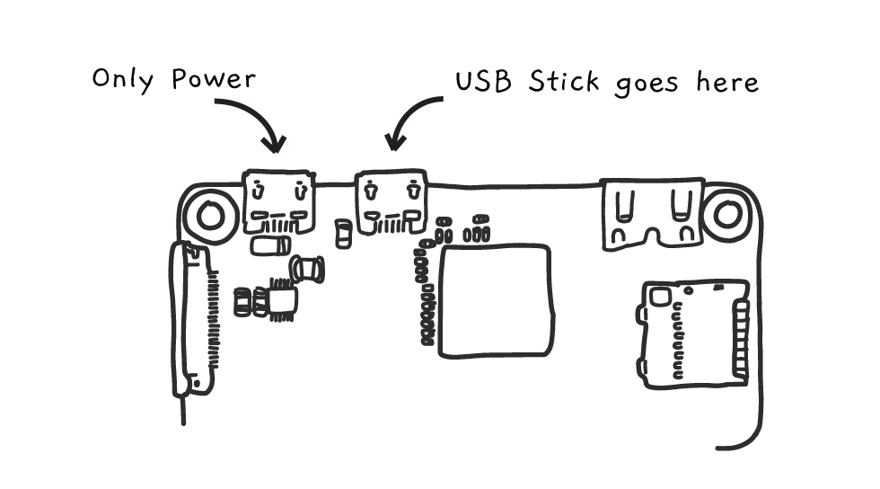
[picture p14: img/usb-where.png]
where to put usb


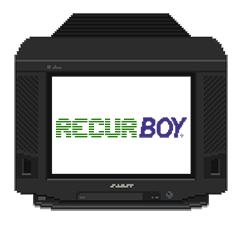
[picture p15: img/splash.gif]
Splash Screen


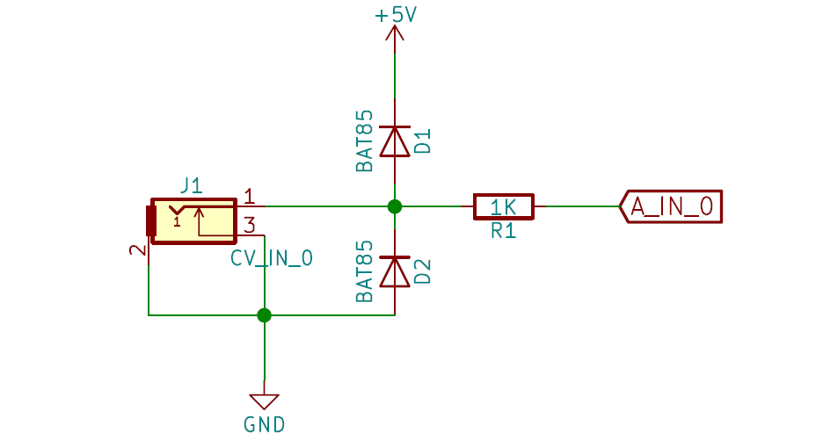
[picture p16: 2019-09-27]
img/cv_schem.PNG

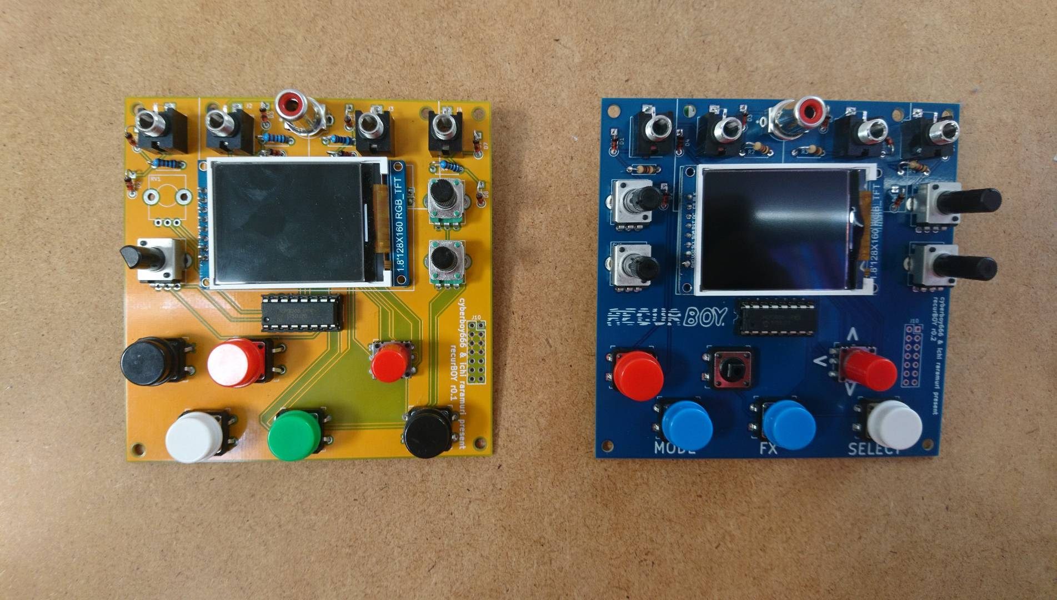
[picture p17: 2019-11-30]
img/72866968_381929056028968_3517549739790827520_n.jpg

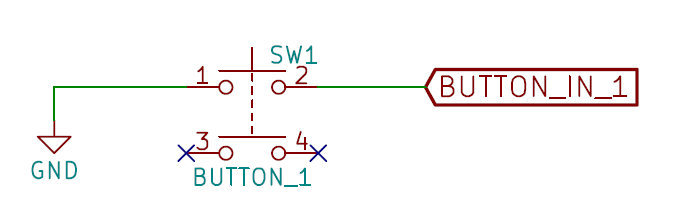
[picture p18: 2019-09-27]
img/button_schem.PNG

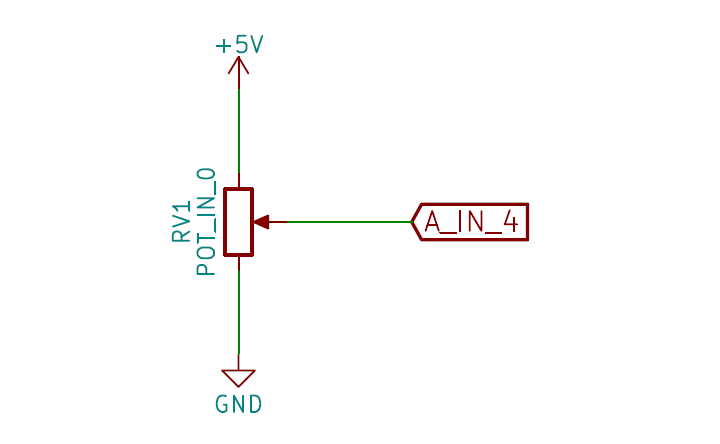
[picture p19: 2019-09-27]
img/pot_schem.PNG

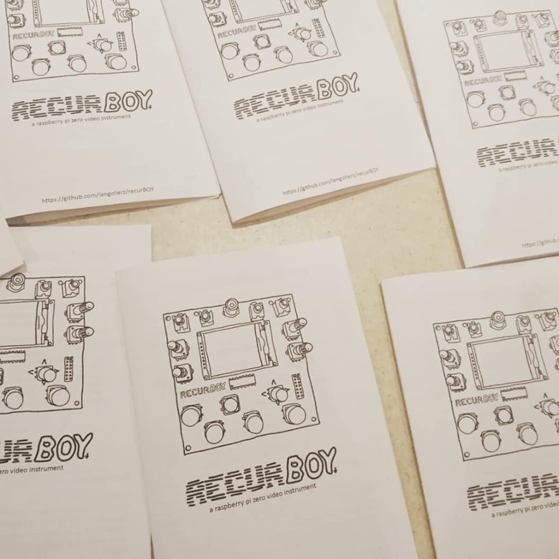
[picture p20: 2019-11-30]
img/72525131_2535621003150633_1056001302670082048_n.jpg

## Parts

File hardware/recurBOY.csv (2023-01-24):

Reference | Quantity | Value | Footprint | Datasheet
D1 D2 D3 D4 D5 D6 D7 D8 | 8 | bat46 | Diode_THT:D_DO-35_SOD27_P5.08mm_Vertical_KathodeUp
J1 J2 J3 J4 | 4 | mono_jack_3.5mm | Connector_Audio:Jack_3.5mm_QingPu_WQP-PJ398SM_Vertical_CircularHoles
J10 | 1 | europower | Connector_PinHeader_2.54mm:PinHeader_2x08_P2.54mm_Vertical
J5 | 1 | display_1.8 | lib_fp:tht_1.8_inch_tft_display
J6 | 1 | Pin_Socket | Connector_PinHeader_2.54mm:PinHeader_1x02_P2.54mm_Vertical
J7 | 1 | rca | lib_fp:tht_vertical_rca | ~
J8 | 1 | 2x20_Socket | Connector_PinHeader_2.54mm:PinHeader_2x20_P2.54mm_Vertical | https://www.raspberrypi.org/documentation/hardware/raspberrypi/schematics/rpi_SCH_3bplus_1p0_reduced.pdf
J9 | 1 | push_5way | lib_fp:tht_sw_5way
R1 R2 R3 R4 | 4 | 1K | Resistor_THT:R_Axial_DIN0207_L6.3mm_D2.5mm_P7.62mm_Horizontal
RV1 RV2 RV3 RV4 | 4 | 10k_pot | lib_fp:Potentiometer_Alps_RK09K_Single_Vertical
SW1 SW2 SW3 SW4 SW5 | 5 | push | Button_Switch_THT:SW_PUSH-12mm
U1 | 1 | mcp3008 | Package_DIP:DIP-16_W7.62mm_LongPads

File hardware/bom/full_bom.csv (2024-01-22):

sku | qty | ref | val | vendor
A-1095 | 8 | D1 D2 D3 D4 D5 D6 D7 D8 | bat46 | tayda
A-2563 | 4 | J1 J2 J3 J4 | mono_jack_3.5mm | tayda
A-2956 | 1 | J10 | europower | tayda
https://www.aliexpress.com/item/32996979276.html | 1 | J5 | display_1.8 | other
A-196 | 1 | J6 | Pin_Socket | tayda
490-RCJ-024 | 1 | J7 | rca | mouser
A-195 | 1 | J8 | 2x20_Socket | tayda
https://www.aliexpress.com/item/4000681560472.html | 1 | J9 | push_5way | other
A-2200 | 4 | R1 R2 R3 R4 | 1K | tayda
A-5531 | 4 | RV1 RV2 RV3 RV4 | 10k_pot | tayda
A-4812 | 5 | SW1 SW2 SW3 SW4 SW5 | push | tayda
A-2470 | 1 | U1 | mcp3008 | tayda
A-1095 | 8 | - | bat46 | tayda
https://www.aliexpress.com/item/1005004605675053.html | 1 | - | sd_card | aliexpress
https://www.aliexpress.com/item/1005002962792811.html | 1 | - | otg_adapter | aliexpress
- | 2 | - | m3_screws | anywhere
- | 2 | - | m3_nuts | anywhere
A-003 | 1 | - | dip16_socket | tayda
A-198 | 1 | - | 2x20_pin_header | tayda

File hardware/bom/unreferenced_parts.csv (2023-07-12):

sku | qty | ref | val | vendor
A-1095 | 8 | - | bat46 | tayda
https://www.aliexpress.com/item/1005004990907467.html | 1 | - | sd_card | aliexpress
https://www.aliexpress.com/item/1005002962792811.html | 1 | - | otg_adapter | aliexpress
- | 2 | - | m3x25mm_screws | anywhere
- | 2 | - | m3_nuts | anywhere
A-003 | 1 | - | dip16_socket | tayda
A-198 | 1 | - | 2x20_pin_header | tayda
A-4815 | 5 | - | A25_tact_caps_12mm | tayda
https://www.aliexpress.com/item/32810107963.html | 1 | - | A11_tact_cap_5way | aliexpress

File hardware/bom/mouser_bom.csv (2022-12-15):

sku | qty | ref | val | vendor
490-RCJ-024 | 1 | J7 | rca | mouser

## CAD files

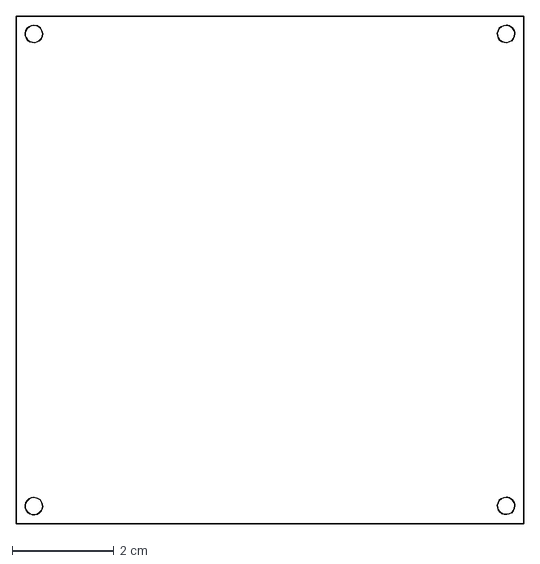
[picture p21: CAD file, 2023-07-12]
panel/back_panel/back_panel-Edge_Cuts.dxf
10.0 x 10.0 cm

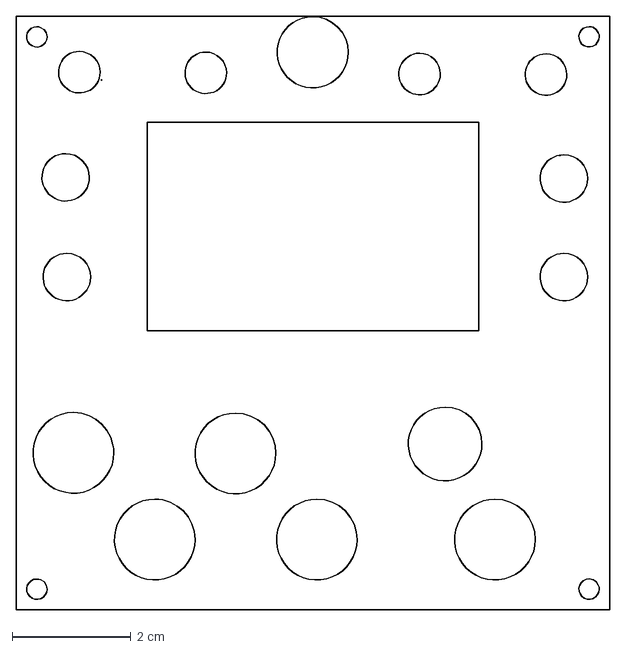
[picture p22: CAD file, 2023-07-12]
panel/default_panel/default_panel-Edge_Cuts.dxf
10.0 x 10.0 cm

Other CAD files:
panel/default_panel/default_panel-F_Silkscreen.dxf

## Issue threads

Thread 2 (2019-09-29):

circuit r0.3 revisions

langolierz, 2019-09-29:
based on the 0.2 boards got some feedback about the layout etc. i will add any more ideas to this issue and consider them for the next run of pcbs

- logo bigger on back ?
- move j8 label for clarity
- put labels j6 and j8 on back, maybe with a hint to see back on front
- ~line the pots with the end jacks~
- ~screen mounting hole is still slightly off (probably 0.5mm - 0.7mm?)~
- ~label symbols ▶ / ■ or ▶ / &#9208; for play button~
- ~swap position of euro-power and circuit name~

langolierz, 2019-10-16:
also use both tv-out and ground pins since 2x1 headers is easier than 1x1 headers to place etc

Closed 2019-11-08.

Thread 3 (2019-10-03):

large lists from usb not showing on the display

cyberboy666, 2019-10-03:
there seems to be some problem with communicating the shader/fx/sample lists from openframeworks to python display when the list is large and from the usb.

i will need to investigate this problem and find a fix - it shouldnt be hard to update the lists but for some reason weird stuff was happening when i tried ...

langolierz, 2019-12-23:
this could be the limit of character length sent over osc -> a solution would be to batch send

BogheMik, 2024-02-21:
Hi, by shortening the names more are displayed.

cyberboy666, 2025-05-08:
fixed in #41

Closed 2025-05-08.

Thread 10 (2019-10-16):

PCB - add labeling play pause on upper left button

guergana, 2019-10-16:
for next revision of pcb

guergana, 2019-10-16:
already addressed in another issue

Closed 2019-10-16.

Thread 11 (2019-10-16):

PCB - add j6 - j8 labels at the bottom

guergana, 2019-10-16:
if possible, to avoid confusion during workshop

guergana, 2019-10-16:
already addressed in another issue, oops

Closed 2019-10-16.

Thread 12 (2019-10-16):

feedback node

langolierz, 2019-10-16:
so far we have a node for 0-input shaders (Shaders) and 1-input shaders (Fx), one idea is to have another node for 2-input shaders where one input is the source and the other input is the last frame, creating the kind of framebuffer feedback that really gets people going ...

langolierz, 2020-06-11:
this is possible currently by using a second texture input in the fx stage

Closed 2020-06-11.

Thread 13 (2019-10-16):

re-check the files on MODE press

cyberboy666, 2019-10-16:
currently if new files are transfered or a usb is inserted it will not be read from the program until after a restart. it would be nice if pressing the mode button triggered this update

cyberboy666, 2023-02-13:
fixed in software release [v2_1_0](https://github.com/cyberboy666/recurBOY/tree/v2.1.0)

Closed 2023-02-13.

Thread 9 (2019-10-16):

play image files?

guergana, 2019-10-16:
several people asked at fubar if still images or gifs could be played.

hacklab01, 2019-10-16:
omxplayer can't play gifs so that's a no go.
Other players like mplayer etc play them properly but overheating is an issue there.

langolierz, 2019-10-16:
i havnt tried yet but there is an extension for openframeworks here which might handle gifs: https://github.com/Geistyp/ofxGif, also it is possible the default ofVideoPlayer (not the omx version) might have a go at it ...

but yes overheating / performance still might be a problem for the pi0

Schum495, 2019-10-23:
Noob question, but how do I get my own video assets playing on the Boi? I looked through the files and didn't notice the repository for it. Also, what type of USB cameras are compatible with Recur Boy?

guergana, 2019-10-23:
Hi, you can play your own files by plugging and usb stick to the Raspberry pi in a /Videos folder at the root. The camera works with an easycap. https://www.amazon.de/Videoaufnahme-Adapter-EasyCap-DC60-USB-2-0/dp/B00SKCI232

Schum495, 2019-10-23:
Much gratitude!!!

On Wed, Oct 23, 2019, 4:10 PM Ichi Rarámuri <notifications@github.com>
wrote:

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

cyberboy666, 2023-02-13:
__partially__ fixed in software release [v2_1_0](https://github.com/cyberboy666/recurBOY/tree/v2.1.0)

playing still images now - iv opened a new issue #23 to keep track of animated gif request (still still havnt tried this yet)

Closed 2023-02-13.

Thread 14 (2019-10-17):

tries to record live video and crashes

cyberboy666, 2019-10-17:
there is code to record samples from the live input, but i removed this since it is to much for the zeros. we found it still tried recording while playing with the live input ...

cyberboy666, 2023-02-13:
fixed in software release [v2_1_0](https://github.com/cyberboy666/recurBOY/tree/v2.1.0)

Closed 2023-02-13.

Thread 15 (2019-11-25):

euro-power header is wrong

langolierz, 2019-11-25:
i just googled eurorack power header - the two results i saw was a 10pin header and a 16pin header. on the scematic / pcb there is a 14pin header - i dont know why or if it is useful like this ...

langolierz, 2019-12-14:
fixd on v0.4

Closed 2019-12-14.

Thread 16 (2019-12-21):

Hdmi output is not correctly sized

cyberboy666, 2019-12-21:
When trying the hdmi output some frame buffers are larger than others - maybe should also try setting the output to sd to make it more usable

cyberboy666, 2023-02-13:
fixed in software release [v2_1_0](https://github.com/cyberboy666/recurBOY/tree/v2.1.0)

Closed 2023-02-13.

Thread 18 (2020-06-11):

revisions to next pcb version

cyberboy666, 2020-06-11:
- add compatibility for slight different model of lcd screen (more available  ) : power to the backlight pin
- re-route to use ground planes on both sides

Closed 2022-09-25.

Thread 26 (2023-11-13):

Flip the orientation of the eurorack power header

dComposer, 2023-11-13:
Standard practice is to have the -12V pins of the power header facing the bottom of the PCB (ie, red stripe down). The fact that the -12V pins are facing the top and there's no stripe on the PCB to denote this makes powering the recurBOY with a eurorack PSU a needlessly risky situation!

cyberboy666, 2023-12-11:
this is a good and valid point - thanks for the suggestion will implement on next revision

cyberboy666, 2025-04-04:
fixed in release #38

Closed 2025-04-04.

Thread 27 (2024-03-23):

Mainbow + recurBOY issues (PAL mode)

hellocatfood, 2024-03-23:
I have a [Mainbow](https://www.etsy.com/uk/listing/1005042852/mainbow-analog-video-synth-eurorack) and I’m having trouble feeding video into it from a recurBOY when in PAL mode.

When I plug the output of the recurBOY into the video input on the Mainbow it shows the video correctly. However, when I turn up the Alpha Symmetry instead of the generated pattern all I see is a grey/white overlay. See video below

Uploading Mainbow⧸recurBOY [BPfSKHQWs-Y].mp4…

What I should be seeing is demonstrated in [the demo video 4](https://www.youtube.com/watch?v=JUSZ0qDWMXo). I have tried feeding video in from other devices and it worked fine, so I’m guessing it’s something to do with the recurBOY/Raspberry Pi?

Both the recurBOY and Mainbow are set to PAL (I’m in the UK). When both devices are set to NTSC it works.

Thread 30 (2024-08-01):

there seems to be a bug when switching from ntsc to pal mode

cyberboy666, 2024-08-01:
the suggested way to switch a raspberry pi video output from ntsc (default) to pal is to power down the unit, remove the sd card and put this into a computer, then open the `config.txt` file inside the `boot` partition.

in here you need to change the `sdtv_mode` from 0 (ntsc) to 2 (pal) - then save the file, eject the card and return it to pi to power back on.

for many years this method worked fine. however recently i have noticed that when i do these exact steps now often when booting back into the pi it just hangs on a black screen with a little cursor in the top left - nothing happens...

i found reflashing the image and setting pal mode before first power up worked fine... but its not ideal !

cyberboy666, 2025-05-08:
fixed in #41

Closed 2025-05-08.

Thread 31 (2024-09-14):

make it easier to tell which direction the diodes should be placed with silkscreen indications

cyberboy666, 2024-09-14:

cyberboy666, 2025-04-04:
fixed in release #38

Closed 2025-04-04.

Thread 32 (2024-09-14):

make it easier with silkscreen / documentation to tell that mcp3008 is a dual footprint part

cyberboy666, 2024-09-14:

cyberboy666, 2025-04-04:
fixed in release #38

Closed 2025-04-04.

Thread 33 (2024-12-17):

Can't load files from USB ...

stilltryin, 2024-12-17:
Hey, first i could load my files from attached usb, but after second boot it didn't work...tried different usb sticks and i build two recurboy same outcome at both...any ideas where to start? maybe format of the usb stick or? Thx

Closed 2025-03-09.

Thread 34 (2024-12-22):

Display images in correct aspect ratio

hellocatfood, 2024-12-22:
Is there a way to display images in their correct aspect ratio? Currently when loading images they distort to fit the whole screen

cyberboy666, 2025-05-08:
fixed in #41

Closed 2025-05-08.

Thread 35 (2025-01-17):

NEW FEATURE: add text overlay mode

cyberboy666, 2025-01-17:
the idea is to display either text files from the usb/sd or live input with a usb keyboard attached.

the pots/cv would control displacement and/or color

there would be two new interface pages (i think to the right of the effect page):

### TEXT

selecting which text file to display from file list - or choose LIVE (if keyboard attached - a special key on keyboard would save current live text to a file) - pots here control text displacement (x_pos, y_pos, width, height)

### FONT

selecting which font that text is in from file list - pots here control text color(hue, sat brightness, alpha)

while in TEXT/FONT pages the FX button will toggle the text on/off instead of the effect...

cyberboy666, 2025-05-08:
fixed in #41

Closed 2025-05-08.

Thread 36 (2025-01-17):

NEW FEATURE: add settings page

cyberboy666, 2025-01-17:
allow user to access some recurBOY settings from the interface.

currently in the interface you can move from a SOURCE page (VIDEO/SHADERS/CAMERA) to EFFECT page by pressing RIGHT on keypad. and back to SOURCE from EFFECT by pressing LEFT on keypad.

im thinking the SETTINGS page would be accessed by pressing LEFT from a SOURCE page. and returned to SOURCE from SETTINGS by pressing RIGHT...

then settings can be navigated the same way as selecting anything on recurboy - with UP, DOWN and SELECT buttons.

some examples of settings to access:

- hdmi/composite output
- pal/ntsc composite output
- 720/480 hmdi output
- 1V/5V cv input
- enable text mode
- show FPS
-  display pixel offset
- restart external input
- shutdown

cyberboy666, 2025-05-08:
fixed in #41

Closed 2025-05-08.

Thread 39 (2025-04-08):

mcp3008 ic should have 0.1uf power cap near it

cyberboy666, 2025-04-08:

cyberboy666, 2025-05-08:
fixed in #41

Closed 2025-05-08.

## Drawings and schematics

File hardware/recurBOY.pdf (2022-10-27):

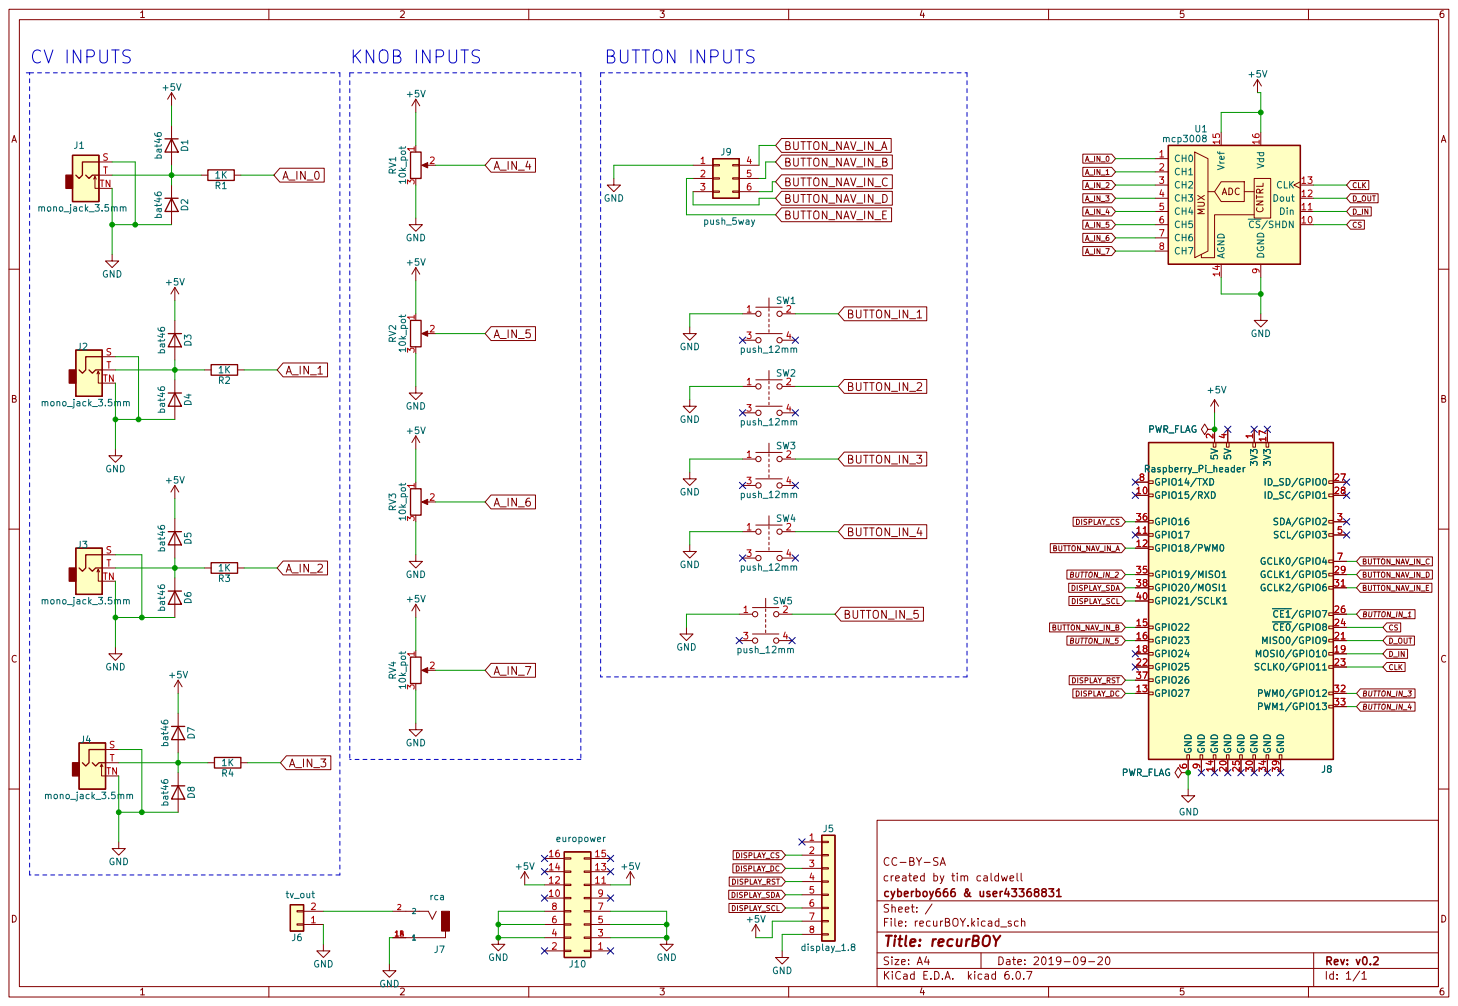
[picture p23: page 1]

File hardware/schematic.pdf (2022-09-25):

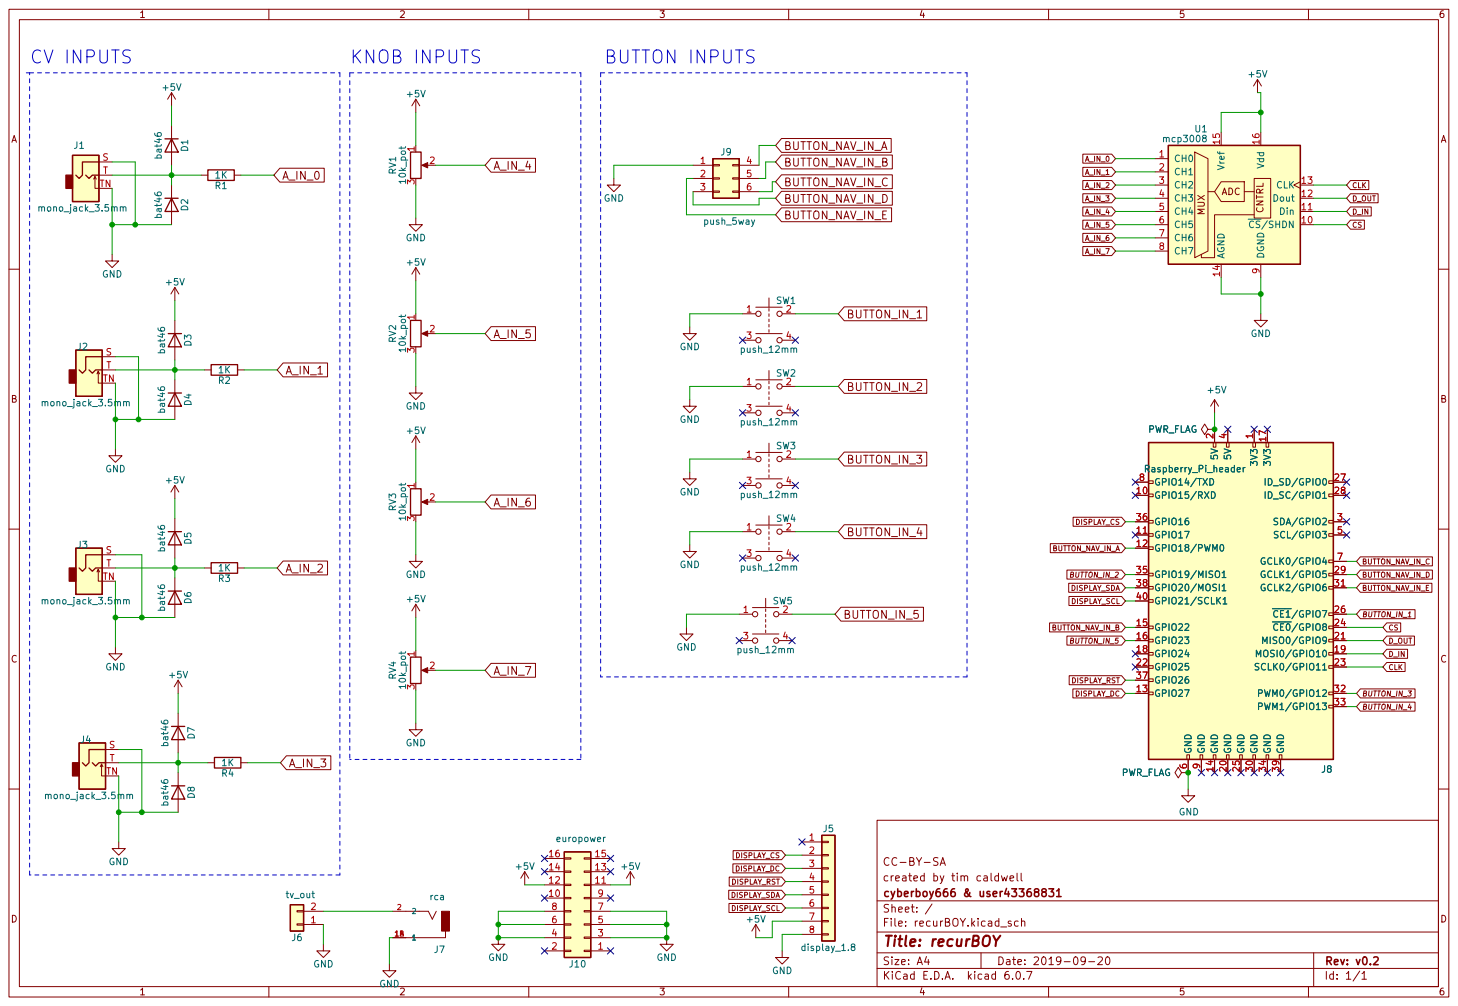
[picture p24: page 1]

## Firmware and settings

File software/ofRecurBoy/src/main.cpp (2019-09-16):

#include "ofMain.h"
#include "ofApp.h"

//========================================================================
int main( ){
    ofSetLogLevel(OF_LOG_VERBOSE);
	//ofSetupOpenGL(1024,768, OF_WINDOW);			// <-------- setup the GL context
    //ofSetupOpenGL(1024,768, OF_WINDOW);
	ofGLESWindowSettings settings;
    settings.setSize(1280, 720);
	settings.setGLESVersion(2);
	ofCreateWindow(settings);


	// this kicks off the running of my app
	// can be OF_WINDOW or OF_FULLSCREEN
	// pass in width and height too:
	ofRunApp( new ofApp());


}

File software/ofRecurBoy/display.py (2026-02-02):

from PIL import Image
from PIL import ImageDraw
from PIL import ImageFont

import ST7735 as TFT
import Adafruit_GPIO as GPIO
import Adafruit_GPIO.SPI as SPI

from pythonosc import osc_server
from pythonosc import osc_message_builder
from pythonosc import dispatcher
import threading
import argparse
import time
import json



def create_display():

    with open('/home/pi/openframeworks10.1/apps/myApps/ofRecurBoy/bin/data/settings.json', 'r') as f:
        settings = json.load(f)

    pixel_offset = settings.get("PIXEL_OFFSET", False)
    print("PIXEL OFFSET: ", pixel_offset)
    width = 130 if pixel_offset else 128 
    height = 161 if pixel_offset else 160
    SPEED_HZ = 4000000

    # Raspberry Pi configuration.
    DC = 27
    RST = 26
    SPI_PORT = 1
    SPI_DEVICE = 2

    disp = TFT.ST7735(
        DC,
        rst=RST,
        spi=SPI.SpiDev(
            SPI_PORT,
            SPI_DEVICE,
            max_speed_hz=SPEED_HZ),
        width=width,
        height=height)
    disp.begin()  # Initialize the display
    return disp


disp = create_display()
# Initialize display.
disp.begin()

# Get a PIL Draw object to start drawing on the display buffer.
draw = disp.draw()

# Load default font.
font = ImageFont.load_default()
font_name = "LiberationMono-Regular.ttf"
font = ImageFont.truetype(font_name, 10)
font_title = ImageFont.truetype(font_name, 16)
font_fx = ImageFont.truetype(font_name, 14)

# Define a function to create rotated text.  Unfortunately PIL doesn't have good
# native support for rotated fonts, but this function can be used to make a
# text image and rotate it so it's easy to paste in the buffer.
def draw_rotated_text(image, text, position, angle, font, fill=(255,255,255),background=(0,0,0) ):
    # Get rendered font width and height.
    draw = ImageDraw.Draw(image)
    width, height = draw.textsize(text, font=font)
    # Create a new image with transparent background to store the text.
    textimage = Image.new('RGBA', (width, height), background + (255,))
    # Render the text.
    textdraw = ImageDraw.Draw(textimage)
    textdraw.text((0,0), text, font=font, fill=fill)
    # Rotate the text image.
    rotated = textimage.rotate(angle, expand=1)
    # Paste the text into the image, using it as a mask for transparency.
    image.paste(rotated, position, rotated)

class Page(object):
    def __init__(self, name):
        self.name = name
        self.menu_list = []
        self.selected_row = 0
        self.list_offset = 0
        self.playing_row =-1
        self.playing = False
        self.title = ""
        self.title_color = (255,0,255)
        self.set_page_based_on_name()

    def set_page_based_on_name(self):
        if(self.name == "VIDEO"):
            self.title = "_VIDEO_"
            self.title_color = (255,0,255) # magenta
        elif(self.name == "PATTERN"):
            self.title = "_PATTERN_"
            self.title_color = (255,255,0) # cyan
        elif(self.name == "EFFECT"):
            self.title = "_EFFECT_"
            self.title_color = (0, 255, 255) # yellow
        elif(self.name == "EXTERNAL"):
            self.title = "_EXTERNAL_"
            self.title_color = (255, 0, 0) # blue
        elif(self.name == "SETTING"):
            self.title = "_SETTING_"
            self.title_color = (255,255,255) # white
        elif(self.name == "TEXT"):
            self.title = "_TEXT_"
            self.title_color = (0,0,255) # red
        elif(self.name == "FONT"):
            self.title = "_FONT_"
            self.title_color = (0,255,0) # green
        elif(self.name == "MESSAGE"):
            self.title = "_MESSAGE_"
            self.title_color = (0,0,255) # red
    
    def get_view_list(self):
        return self.menu_list[self.list_offset:self.list_offset + 6] 


class Display(object):
    def __init__(self):
        self.osc_server = self.setup_osc_server()
        self.update_count = 0
        self.pages = {"VIDEO": Page("VIDEO"), "PATTERN": Page("PATTERN"), "EFFECT": Page("EFFECT"), "EXTERNAL": Page("EXTERNAL"), "TEXT": Page("TEXT"), "FONT": Page("FONT"), "SETTING": Page("SETTING"), "MESSAGE": Page("MESSAGE")}
        self.current_page_name = 'VIDEO'


    @staticmethod
    def get_state_symbol(state):
        if state:
            return '>'  #'▶ 
        else:
            return '■' #'■'        

    def create_this_screen(self):
        # print title
        thisPage = self.pages[self.current_page_name]
        title = thisPage.title + "_" + self.get_state_symbol(thisPage.playing)
        draw_rotated_text(disp.buffer, title, (110, 10),270, font_title, fill=(0,0,0), background=thisPage.title_color)
        if self.pages["EFFECT"].playing and self.pages["TEXT"].playing:
            draw_rotated_text(disp.buffer, '[ft]', (110, 128),270, font_fx, fill=(0,0,0), background=(255,255,255))
        elif self.pages["EFFECT"].playing:
            draw_rotated_text(disp.buffer, '[fx]', (110, 128),270, font_fx, fill=(0,0,0), background=(0,255,255))
        elif self.pages["TEXT"].playing:
            draw_rotated_text(disp.buffer, '[xt]', (110, 128),270, font_fx, fill=(0,0,0), background=(255,0,0))
        # print content
        for i, value in enumerate(thisPage.get_view_list()):
            if i == thisPage.selected_row - thisPage.list_offset:
                draw_rotated_text(disp.buffer, value, (110 - 15 - i*15, 10) ,270, font, fill=(0,0,0), background=(255,255,255))        
            elif i == thisPage.playing_row - thisPage.list_offset:
                draw_rotated_text(disp.buffer, value, (110 - 15 - i*15, 10) ,270, font, fill=(0,0,0), background=thisPage.title_color)   
            else:
                draw_rotated_text(disp.buffer, value, (110 - 15 - i*15, 10) ,270, font, fill=(255,255,255), )

    
    def setup_osc_server(self):
        server_parser = argparse.ArgumentParser()
        server_parser.add_argument("--ip", default="127.0.0.1", help="the ip")
        server_parser.add_argument("--port", type=int, default=9000, help="the port")
        
        server_args = server_parser.parse_args()

        this_dispatcher = dispatcher.Dispatcher()

        this_dispatcher.map("/LIST/*", self.set_list)
        this_dispatcher.map("/CLEAR/LIST/*", self.clear_list)
        this_dispatcher.map("/SELECTED_ROW/*", self.set_selected_row)
        this_dispatcher.map("/PLAYING_ROW/*", self.set_playing_row)
        this_dispatcher.map("/PLAYING/*", self.set_playing)
        this_dispatcher.map("/CURRENT_PAGE", self.set_current_page)
        this_dispatcher.map("/RESTART_DISPLAY", self.restart_display)

        server = osc_server.ThreadingOSCUDPServer((server_args.ip, server_args.port), this_dispatcher)
        server_thread = threading.Thread(target=server.serve_forever)
        server_thread.start()
        return server
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

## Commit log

2019-08-19 added kicad files and gerbers
    [recurBOY-B.Cu.gbl, recurBOY-B.Mask.gbs, recurBOY-B.SilkS.gbo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]
2019-09-16 fixed index and highlight current playing
    [display.py, ofApp.cpp]
2019-09-20 updated kicad files and added booklet info
2019-09-21 read files from usb only in correct format
    [ofApp.cpp]
2019-09-23 adding record to camera mode
2019-09-27 add play button
2019-09-29 getting analog in working and exit code
    [recurBOY.kicad_pcb, recurBOY.sch, recurBOY_pg2.sch]
2019-10-05 info on copying videos from win to raspberry
2019-11-05 added 16pin socket to list
2019-11-05 updated raspberry pi zero price
2019-11-30 adding 1v clip and adc read setting
2019-12-01 make framerate a setting
2019-12-01 added show framerate option
2019-12-10 added socket io installation instructions
2022-09-25 refacter folder system - add kicad files to the project
    [full_bom.csv, mouser_bom.csv, recurBOY.kicad_pcb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]
2022-10-27 made pot holes bigger , moved fp libs around a bit
    [recurBOY.kicad_pcb, recurBOY.kicad_sch]
2022-12-15 update bom
    [full_bom.csv, mouser_bom.csv, tayda_bom.csv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]
2023-01-24 update version to v0_7_1 + some WIP panel work
    [back_panel-B_Cu.gbr, back_panel-B_Mask.gbr, back_panel-B_Paste.gbr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]
2023-01-24 file renames
    [recurBOY-B_Cu.gbl, recurBOY-B_Mask.gbs, recurBOY-B_Silkscreen.gbo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]
2023-01-29 update panel with changes based on last one
    [default_panel-B_Cu.gbr, default_panel-B_Mask.gbr, default_panel-B_Paste.gbr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]
2023-02-12 update booklet version
    [default_panel.kicad_pcb]
2023-07-12 add panel stuff
    [back_panel-Edge_Cuts.dxf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]
2023-08-31 add dip+soic on board for mcp3008
    [recurBOY-B_Cu.gbl, recurBOY-B_Mask.gbs, recurBOY-B_Silkscreen.gbo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]
2023-08-31 remove gerber unzipped
    [recurBOY-B_Cu.gbl, recurBOY-B_Mask.gbs, recurBOY-B_Silkscreen.gbo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]
2025-01-29 some panel stuff
    [default_panel-B_Cu.gbr, default_panel-B_Mask.gbr, default_panel-B_Paste.gbr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]
2026-02-02 pull backlight pin high
